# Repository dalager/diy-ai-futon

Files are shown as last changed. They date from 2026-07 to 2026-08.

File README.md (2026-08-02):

# Sengebund — LET variant (futon 180 × 200 cm)

Parametrisk CAD-projekt for en let, ubehandlet **futon-sengebund**: slank 45×95-ramme,
17 kvadratiske 45×45-lameller der flugter med rammens overkant, og en langsgående
midterdrager (45×45) på ét midterben. Ben skæres af afskær (45×95) — ingen
trykimprægneret stolpe, ingen lim. Udvendige mål = madrasmålet (180 × 200 cm), så
madrassen ligger plant af med kanten.

Hele modellen bygges headless i **FreeCAD** fra ét parametersæt, og tegninger,
boreplan, renderinger og en samlet PDF genereres af scripts.

| Isometrisk | Understel (lameller skjult) |
|:---:|:---:|
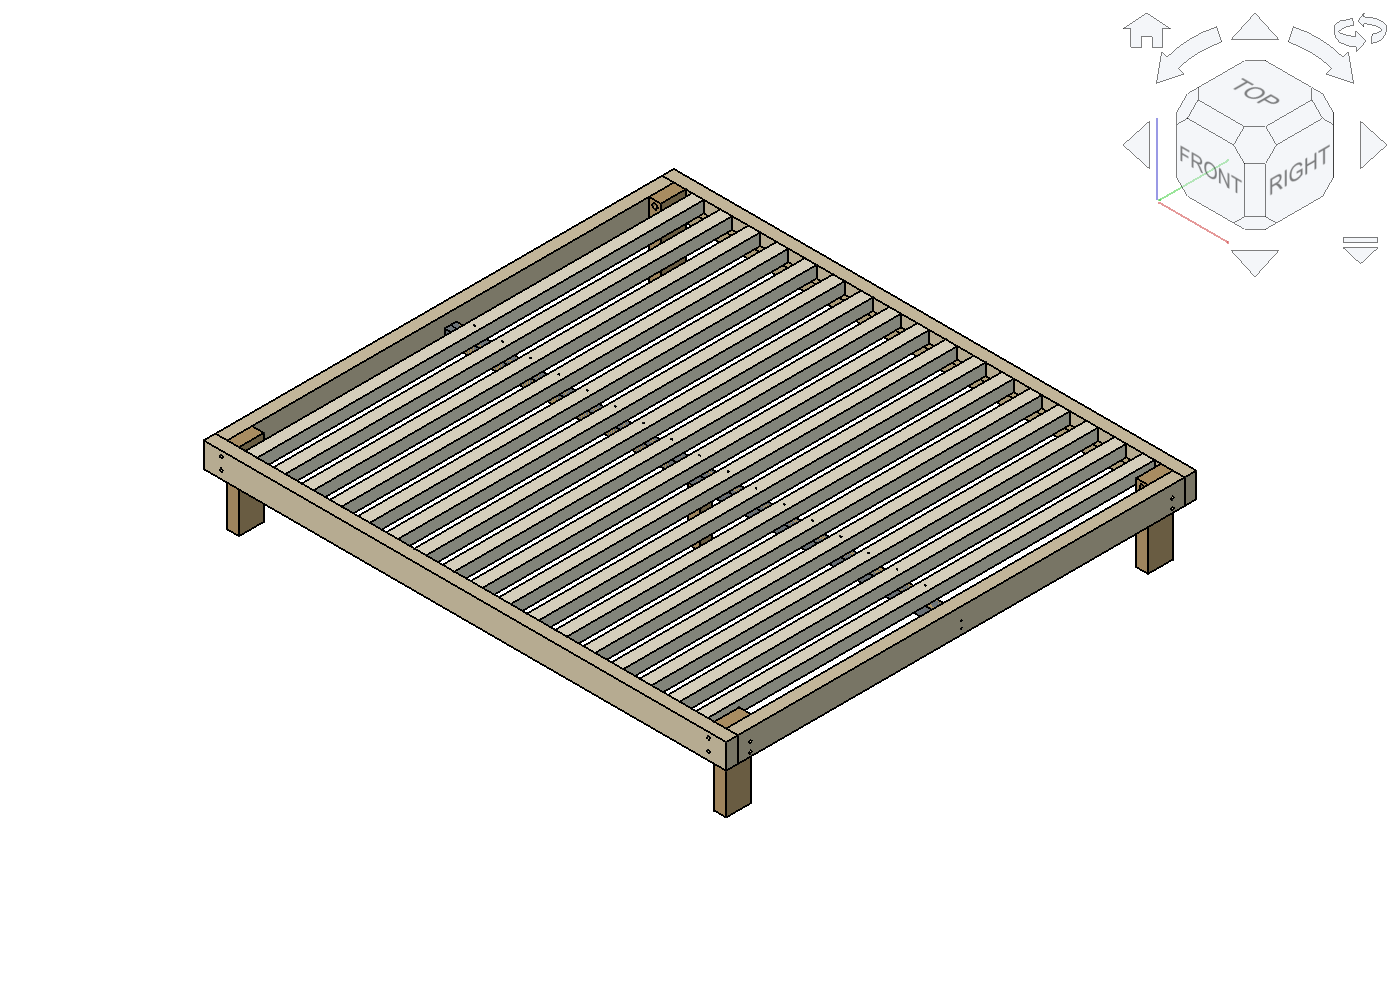
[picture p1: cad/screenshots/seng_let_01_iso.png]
Isometrisk
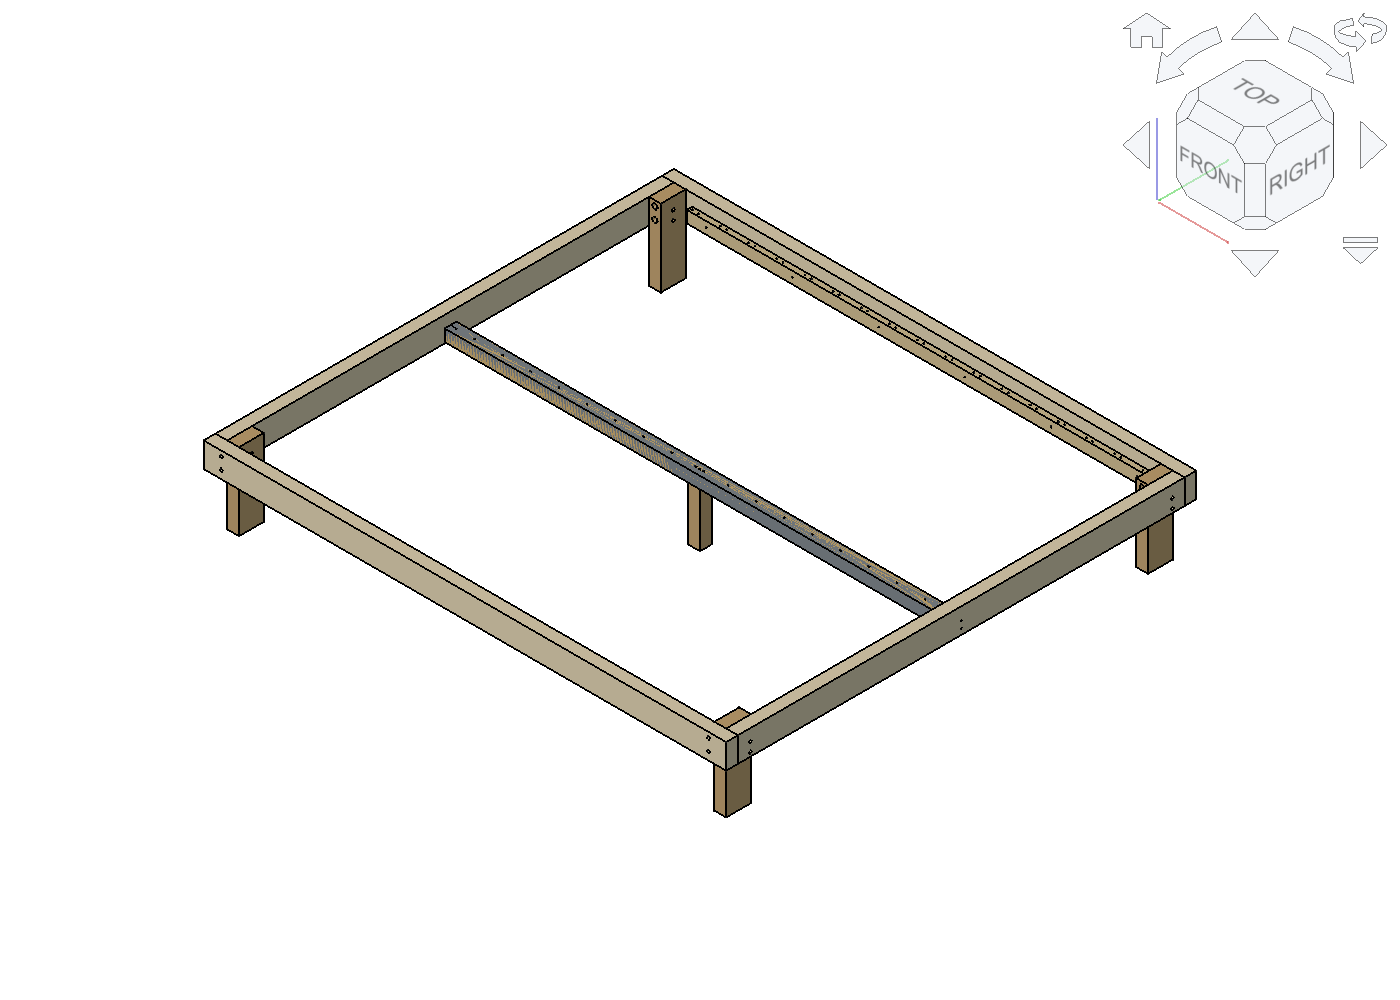
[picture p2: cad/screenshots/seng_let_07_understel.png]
Understel
|  |  |

## Kort specifikation

| | |
|---|---|
| Udvendige mål | 180 × 200 cm (= madras, flush) |
| Vægt | ~48 kg (fyr/gran) |
| Ramme | 45 × 95, boltet i hjørnerne (M10) |
| Lameller | 17 × 45×45, flugter med rammens overkant |
| Midtersupport | drager 45×45 + ét midterben |
| Frihøjde | 200 mm under ramme / 205 mm under drager (robotstøvsuger) |
| Ben | 4 × 45×95 af **afskær** ♻️ (ubehandlet, ingen lim) |
| Pris (jul. 2026) | ~1.650 kr (træ prischecket, skruer anslået) |

## Dokumenter

- **[byggevejledning.md](byggevejledning.md)** — vejledningen til udlevering: indkøb,
  værktøj, skæreplan, boring, samling trin for trin, kontrol og statik-tjek.
- **[docs/dokumentation.pdf](docs/dokumentation.pdf)** — byggevejledningen
  som A4-PDF med renderinger og de fire målsatte tegninger bagest (genereres, se nedenfor).
- **[designnoter.md](designnoter.md)** — arbejdsnote uden for PDF'en: hvorfor
  konstruktionen ser ud som den gør, statik, dimensionering, forkastede løsninger og
  indkøbsregnskab.

## Projektstruktur

```
seng/
├── byggevejledning.md            # byggevejledning (kilde til PDF'en)
├── designnoter.md                # arbejdsnote (valg, statik, indkøbsregnskab)
├── scripts/
│   ├── build_bed_let.py          # bygger 3D-modellen -> .FCStd + .step
│   ├── make_drawing_let.py       # målsat tegning -> docs/tegning.svg
│   ├── make_drilling_plan_let.py # boreplan -> docs/boreplan.svg
│   ├── add_drawing_page_let.py   # TechDraw-sider ind i .FCStd
│   └── make_pdf_let.py           # byggevejledning -> PDF (+ tegninger bagest)
├── cad/                          # kun CAD-kilder
│   ├── seng_let.FCStd            # FreeCAD-model (parametrisk, med huller)
│   ├── seng_let.step             # neutral CAD-udveksling
│   └── screenshots/              # 8 FreeCAD-renderinger (.png)
└── docs/                         # genererede tegninger + PDF
    ├── tegning.svg               # målsat tegning
    ├── boreplan.svg              # boreplan (paneler A-D)
    ├── liste_boreplan.svg        # boreplan, støttelistens lamelhuller
    ├── drager_boreplan.svg       # boreplan, midterdrager -> endestykke (vinkelbeslag)
    └── dokumentation.pdf         # byggevejledningen
```

`docs/` rummer desuden referencefotos af beslag og skruer (`*.png`), som er
git-ignorerede — kun de genererede tegninger og PDF'en versionsstyres.

## Genopbygning af hele kæden

Alt afledes af parametrene øverst i `scripts/build_bed_let.py` (mål, antal lameller,
profiler). Ret dem og genkør kæden i rækkefølge:

```bash
# 1. Byg 3D-modellen (headless FreeCAD) -> cad/seng_let.FCStd + .step
freecad.cmd scripts/build_bed_let.py

# 2. Målsat tegning (ren Python) -> docs/tegning.svg
python3 scripts/make_drawing_let.py

# 3. Boreplan (ren Python) -> docs/boreplan.svg + docs/drager_boreplan.svg
python3 scripts/make_drilling_plan_let.py

# 4. TechDraw-sider ind i .FCStd (headless FreeCAD)
freecad.cmd scripts/add_drawing_page_let.py

# 5. Byggevejledning som PDF (byggevejledning.md + de fire tegninger bagest)
~/.pyenv/versions/3.12.3/bin/python scripts/make_pdf_let.py
```

### Renderinger (FreeCAD GUI)

De 8 screenshots i `cad/screenshots/` tages i FreeCAD-GUI'en (via freecad-MCP), fordi
farver og kamera kræver et grafisk miljø. Efter en headless genopbygning (trin 1)
skal modellen genindlæses i GUI'en, træfarverne påføres pr. byggegruppe, filen gemmes,
og de 8 views eksporteres med `View3DInventor.saveImage(...)`.

Farvepaletten (matcher tegningerne):

| Del | Farve |
|-----|---|
| Ramme | `#d8c9a8` |
| Ben (inkl. midterben) | `#b99763` |
| Støttelister | `#c9b487` |
| Lameller | `#efe7d3` |
| Midterdrager | `#c2a266` |

## Afhængigheder

- **FreeCAD** (snap: `freecad.cmd` til headless build; GUI til renderinger).
- **freecad-mcp** ([neka-nat/freecad-mcp](https://github.com/neka-nat/freecad-mcp)) —
  renderingstrinnet styres via FreeCAD-MCP-serveren, så en agent/klient kan genindlæse
  modellen, sætte farver og kalde `saveImage(...)` i den kørende FreeCAD-GUI.
  **Serveren er ikke checket ind i dette repo** (ligger i `deps/freecad-mcp`, som er
  git-ignoreret) — klon den fra upstream og konfigurér den i `.mcp.json`; FreeCAD-GUI'en
  skal køre med MCP-addon'et aktivt:
  ```bash
  git clone https://github.com/neka-nat/freecad-mcp.git deps/freecad-mcp
  ```
  (Selve build- og tegningsscriptene kræver **ikke** MCP — kun de 8 screenshots i
  `cad/screenshots/`.)
- **Python** til tegningerne (kun standardbibliotek).
- **PDF:** `markdown`, `pymdown-extensions` og `weasyprint` — installeret i pyenv-miljøet
  `~/.pyenv/versions/3.12.3`. Kør `make_pdf_let.py` med netop den python. Fonte:
  DejaVu Sans Mono (ASCII-diagrammer) + Noto Color Emoji (♻️ ✅ ⚠️).

## Noter

- **Træfarver er ikke persistente over en headless genopbygning:** trin 1 skriver et
  nyt `.FCStd` uden ViewObject-farver (headless FreeCAD kan ikke sætte dem). Påfør dem
  igen i GUI'en efter genopbygning, før du tager screenshots.
- **Midterdrager 45×45** er et bevidst valg: den flush lamel ville med en 45×70-drager
  kun give 180 mm frihøjde under midten; 45×45 bevarer 205 mm og bruger samme profil
  som lamellerne. Til gengæld er drageren et grænsetilfælde omkring L/300 — se
  statik-afsnittet i [designnoter.md](designnoter.md).

## Licens

[MIT](LICENSE) © 2026 Christian Dalager

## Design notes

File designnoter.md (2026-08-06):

# Designnoter — sengebund LET, futon 180 × 200 cm

Arbejdsnote til **hvorfor** sengen ser ud som den gør: konstruktionsvalg, statik,
dimensionering, forkastede løsninger og indkøbsregnskab.

**[byggevejledning.md](byggevejledning.md) er facit** for mål, hulplaceringer,
materialeliste og fremgangsmåde. Denne note gentager dem ikke — ret altid vejledningen
først, og skriv kun begrundelsen her. Selve geometrien kommer fra
`scripts/build_bed_let.py`, og CAD-modellen (`cad/seng_let.FCStd`) er sandheden om
hulplaceringer.

## Parametersæt

Alt afledes af `P` i `scripts/build_bed_let.py`:

| Parameter | Værdi | Bemærkning |
|---|---|---|
| `clearance` | 200 | frihøjde til gulv |
| `rail_h` / `rail_t` | 95 / 45 | rammens profil (var 120 i den tunge variant) |
| `outer_len` | 2000 | = madraslængden, flush |
| `inner_w` | 1710 | → udvendig bredde 1800 = madrasbredden |
| `ledger_t` / `ledger_h` | 21 / 45 | støtteliste, 45 mm står lodret |
| `slat_t` / `slat_h` | 45 / 45 | kvadratisk lamel |
| `n_slats` | 17 | → c/c 107,8 mm, spalte 62,8 mm |
| `drager_t` / `drager_h` | 45 / 45 | samme profil som lamellerne |

Afledte kotehøjder: soveflade og rammens overkant 295, lamel-underkant og
støtteliste-overkant 250, rammens underkant 200, dragerens underkant 205.

## Konstruktionsvalg

**Udvendige mål = madrasmålet.** Madrassen ligger plant af med kanten i stedet for at være
indelukket af en liste. Det gør rammen til det synlige møbel og sparer 90 mm i begge
retninger. Konsekvensen er, at lamellerne skal flugte med rammens overkant, ikke ligge nede
i den.

**Kvadratiske 45×45-lameller.** Slankhed 1:1 kan ikke vælte, så dominoeffekten fra høje,
tynde lameller findes ikke, og skruerne i enderne er ren lås uden at bære vægt. Prisen er,
at en 45×45 ikke kan spænde 1710 mm alene — den kræver midtersupport. Lamellerne er også
den dyreste post i materialelisten (45×45-reglar er dyre pr. bræt).

**Midterdrager på ét midterben.** Halverer det frie lamelspænd fra 1710 til ~810 mm, og
det er den ene ændring, der gør de kvadratiske lameller mulige. Lamellerne er kontinuerte
over drageren, hvilket gør dem stivere end to fritliggende fag.

**Drager 45×45 frem for 45×70 på højkant.** Kvadratisk drager holder frihøjden på 205 mm
under midten; en 45×70 med samme overkant ender i kote 180 og bryder altså 20 cm-kravet fra
robotstøvsugeren. Det koster stivhed — se statikken. Sidegevinst: kun to reglar-tværsnit i
hele projektet, 45×45 og 45×95.

**20 cm frihøjde** er sat af støvsugerrobotten, ikke af æstetikken. Dragerens underkant
ligger 5 mm over rammens underkant, så der er fri passage overalt.

**Ben af afskær.** Der fandtes ingen firkantet, ubehandlet stolpe hos jem&fix, Silvan eller
Bauhaus — alle massive stolper er trykimprægnerede eller malede. Afskærene fra vanger,
endestykker og drager giver præcis de fem ben, sengen skal have, og resultatet er 100 %
ubehandlet og lim-frit. Ben-tværsnittet 45×95 er slankt for et sengeben, men rammen er en
stiv boltet kasse, så benene står i ren tryk.

**Boltede hjørner, ikke skruede.** Fire gennemgående bolte pr. hjørne kan efterspændes,
når ubehandlet fyr svinder det første år. Skruer i endetræ kan ikke. Det er også derfor,
vange-aksen har kontramøtrik.

## Statik

Fyr, E ≈ 10 GPa, regnet på CAD-modellens geometri. Komfortgrænsen L/300:

| Del | Frit spænd | Nedbøjning ved fuld last | L/300 |
|-----|---|---|---|
| Lamel 45×45 | 810 mm | ~1,7 mm (50 kg punktlast midt på ét fag) | 2,7 mm |
| Midterdrager 45×45 | 2 fag à 955 mm | ~3–4 mm pr. fag | ~3,2 mm |
| Vange 45×95 | 1910 mm | 1–2 mm | ~6,4 mm |

**Drageren er et grænsetilfælde** lige omkring L/300 — designets svageste punkt.
Vurderingen er, at det er uproblematisk under en eftergivende futon, men det er et bevidst
valg for at holde frihøjden. Vil man have margin: et ekstra midterben koster kun et hul og
ingen frihøjde; 45×70 på højkant er stivere, men sender frihøjden under midten ned på
180 mm.

Vangen er kraftigt overdimensioneret, og drageren afstiver den desuden på midten.

**Bolte:** totallasten er ~2,3 kN fordelt på fire hjørner = ~600 N pr. hjørne på to bolte.
Grænsen sættes ikke af bolten (en M8 tåler ~8,8 kN i forskydning) men af **træets
hulrandstyrke**: 8 mm × 45 mm × ~25 MPa ≈ 9 kN for M8, ~11 kN for M10. Begge ligger 15–30
gange over behovet, så de 2 mm boltdiameter er uden betydning. Det, der betyder noget, er
**skivens størrelse** — en M8-planskive er kun Ø16, og møtrikken trækker sig ind i træet.
Derfor Ø24 karosseri-/firkantskive på endestykke-aksen.

## Skruerne — hvorfor tre længder

103 skruesamlinger: **85 × 4,5×60**, **12 × 4,5×50**, **6 × 5×80**.

- **4,5 × 60** til lamel → liste og lamel → drager. 45 mm nær-del + 15 mm fat. Begge
  samlinger *hviler*, så skruen bærer nul vægt og er ren lås; 15 mm i sidetræ er rigeligt.
- **4,5 × 50** til støtteliste → vange. Den eneste samling, der går **vandret** gennem
  listens 21 mm: 21 + 45 = 66 mm stak, så en 70'er stikker 4 mm ud på vangens yderside, og
  en 60'er efterlader kun 6 mm. 50 giver 29 mm fat og 16 mm margin.
- **5 × 80** til drager → endestykke og drager → midterben. De eneste samlinger i
  **endetræ**, hvor holdeevnen er 50–75 % af sidetræs: 35 mm fat i stedet for 15. Der er
  ubegrænset plads bagved (drageren 1910 mm, midterbenet 205 mm), så længden koster
  ingenting.

**Forboringsreglerne** bag tallene i vejledningen, i fyr/gran: gennemgang = skruediameter
+ 0,5 mm; pilot ≈ 65 % af skruediameteren; forsænkning Ø ≈ 2 × skruediameteren.
Undtagelsen er 5×80-skruerne, hvis hoved er Ø10 — dér skal forsænkningen være Ø11, for en
Ø10-forsænkning er lige præcis for lille. 4,5-skruerne har Ø9-hoved, hvor Ø10 rækker.

**Delgevind redder ikke samlingen — forboringen gør.** En 4,5×60 delgevind har kun ~20–25
mm glat skaft, men skruen skal gennem 45 mm nær-del, så gevindet starter inde i nær-delen
alligevel. Det er Ø5-gennemgangshullet, der lader gevindet spille frit og hovedet trække
delene sammen. Delgevind er en fordel oveni, ikke en erstatning. Samme grund til at listens
huller **skal** være Ø5 og ikke Ø4: med Ø4 griber gevindet i listen og jækker de to dele
fra hinanden i stedet for at spænde dem sammen.

**Krav ved genkøb:** spånskrue/universalskrue, undersænket hoved, Torx, delgevind.
Elforzinket rækker indendørs; rustfri er kun nødvendigt udendørs, og Impreg®+ er en
udendørs-coating — mere end nødvendigt, men uskadeligt. Vinkelbeslagene er undtagelsen:
beslagskruer med **fladt** hoved, da en undersænket skrue trækker sig ned i beslagets hul
og kan flække det.

## Bolteakserne

Fordi hjørnebenet er 45×95 af afskær, er de to akser forskellige:

**Vange-aksen: M10 × 160** gennem vange (45) + ben (95) = 140 mm træ. Der stikker 20 mm ud
på benets inderflade, hvor skive 2,5 + møtrik 8 + kontramøtrik 8 = 18,5 mm — reelt plant,
ingen forsænkning. Kontramøtrikken er der, fordi ubehandlet fyr svinder, og boltede
træsamlinger løsner sig, når træet krymper. Alternativ: hattemøtrik, der dækker gevindet
helt.

**Endestykke-aksen: M8 × 100** gennem endestykke (45) + ben (45) = 90 mm. Møtrik + Ø24
skive sidder fladt på indersiden. Kun **1,5 mm gevind til overs**, så ingen kontramøtrik og
ingen nyloc på den akse (en M8 nyloc er ~8 mm høj og løber tør for gevind) — og hjørnet
skal presses helt sammen, før møtrikken sættes på. Boltene sidder ved x < 90, mens første
lamel starter ved x = 115, så møtrikkerne går fri af lamelfeltet.

**Hullerne er Ø12 og Ø10, ikke Ø11 og Ø9.** De "rigtige" størrelser er ikke altid til at
skaffe, så næste almindelige størrelse op blev valgt. To konsekvenser: bræddeboltens
firkanthals (M10 ~11,9 mm, M8 ~9,2 mm) **bider ikke** længere, så bolten skal holdes med en
tang, når møtrikken spændes — og marginen i boltkrydset faldt fra 5 til **4 mm** træ mellem
de to huller (de krydser vinkelret med 15 mm lodret afstand). Derfor kravet om vinkelret
boring og om at bore alle fire huller i et ben, før nogen bolt sættes i.

## Forkastede løsninger

Samlet her, så byggevejledningen ikke skal diskutere med sig selv:

| Forkastet | Erstattet af | Hvorfor |
|---|---|---|
| Ramme 45×120 | 45×95 | vægt og udseende; 95 rækker statisk, når der er drager |
| Drager 45×70 på højkant | 45×45 | frihøjde 205 mm under midten; koster stivhed |
| Vinkelbeslag + 6×120 til midterbenet | 2 × 5×80 lodret ned | kravet gjaldt kun den 70 mm høje drager; den 45 mm høje giver 35 mm fat |
| M10 × 140 på vange-aksen | M10 × 160 | 140 mm bolt i 140 mm træ = nul gevind til møtrikken |
| Ø20-lomme i benets inderside | ingen forsænkning | en M10-møtrik kræver en top på 23–25 mm, som ikke kommer ned i Ø20; en større lomme bryder ind i endestykke-boltens hul 15 mm under. **Ø20-forstnerboret er derfor ude af værktøjslisten** |
| Ø11/Ø9 bolthuller | Ø12/Ø10 | kan ikke altid skaffes; koster 1 mm i boltkrydset og firkanthalsens greb |
| Trykimprægneret stolpe til ben | afskær 45×95 | ingen ubehandlet firkantstolpe fandtes; ubehandlet og lim-frit var kravet |
| Kombineret undersænkbor | løs kegleforsænker 90° Ø16 | nær-del og fjern-del skal have to forskellige diametre i samme hul |

Der findes intet mellem M10×140 og ×160: en ×120 når ikke gennem de 140 mm træ, og næste
trin op er ×200, som ville stritte 60 mm ud.

## Indkøbsregnskab

Priser fra Silvan.dk (juli 2026, ekskl. levering). Alt er købt hos Silvan bortset fra
vange-boltene.

### Træ — 1.376,40 kr

| Vare | Antal | Pris/stk | I alt |
|---|---|---|---|
| [Reglar 45×45×2400 ubeh.](https://www.silvan.dk/produkt/froeslev-reglar-45x45x2400-mm-ubehandlet-hoevlet-7700-9804949) | 18 | 64,80 | 1.166,40 |
| [Reglar 45×95×2400 ubeh.](https://www.silvan.dk/produkt/froeslev-reglar-45x95x2400-mm-ubehandlet-hoevlet-7700-9804953) | 4 | 43,80 | 175,20 |
| [Forskalling 21×45×2400 ubeh.](https://www.silvan.dk/produkt/froeslev-forskalling-21x45x2400-mm-ubehandlet-hoevlet-7700-9804930) | 2 | 17,40 | 34,80 |
| Ben (4 hjørne + 1 midter) | 0 | — | 0 |

### Skruer, bolte og beslag — købt hos Silvan

| Vare | Varenr. | Pakke | Bruges | Tilovers |
|---|---|---|---|---|
| Simpson TTZNFS 4,5 × 60 | 74485 | 200 stk | 85 | 115 |
| Simpson TTZNFS 4,5 × 50 | 74484 | 200 stk | 12 | 188 |
| Simpson TTZNFS 5,0 × 80 | 76540 | 100 stk | 6 | 94 |
| Simpson TTUFP 4,0 × 20 beslagskruer | 74519 | 200 stk | ~16 | ~184 |
| KRAM bræddebolt M8 × 100 m/ møtrikker | 6774056 | 12 stk | 8 | 4 |
| KRAM spændeskive M8, 8,4 × 24 × 2,0 | 6774773 | 30 stk | 8 | 22 |
| KRAM spændeskive M10, 10,5 × 30 × 2,5 | 6774774 | 15 stk | 8 | 7 |
| Simpson AC35350 vinkelbeslag | — | 2 stk | 2 | 0 |

Overskuddet er stort, fordi skruerne ikke fandtes i mindre pakker i de længder. De faktiske
priser på skruer og beslag er ikke registreret.

### Mangler — hentes hos jem&fix

| Vare | Antal | Pris |
|---|---|---|
| NKT bræddebolt DIN 603 M10 × 160, 2-pak à 39,95 | 8 stk (4 pk) | **159,80 kr** |
| Løse M10-møtrikker til kontramøtrik | 8 | ~25 kr |

**I alt ca. 1.650 kr** for en 100 % ubehandlet, lim-fri sengebund med ben af genbrugte
afskær.

## Åbne punkter

- **Vinkelbeslag:** Simpsons datablad anbefaler 2 beslag pr. samling (ét i hver side af
  drageren). Der er købt 2 i alt, altså ét pr. ende. To ekstra beslag koster lidt og øger
  sikkerhedsmarginen på den samling, hvis anbefalingen skal følges fuldt ud.
- **Dragerens nedbøjning** ligger på L/300-grænsen. Bør vurderes efter en sæsons brug.
- **De 2 skruer ned i midterbenet** sidder ±15 mm fra midten i CAD-modellen, altså 7,5 mm
  fra benets kant i endetræ. Bores der i hånden, kan de flyttes ind til ±10 mm — så skal
  dragerens gennemgangshuller flyttes tilsvarende.
- **Skruepriserne** er ikke prischecket, så totalen er et skøn.

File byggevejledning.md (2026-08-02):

# Sengebund til futon 180 × 200 cm

Let, ubehandlet futon-sengebund i fyr/gran: slank **45×95-ramme** boltet i hjørnerne,
**17 kvadratiske 45×45-lameller** der flugter med rammens overkant, og en langsgående
**midterdrager på ét midterben**, der halverer lamelspændet. Udvendige mål er
madrasmålet, så madrassen ligger plant af med kanten — ingen liste op om.

Ingen lim, ingen trykimprægneret træ og ingen avanceret træbearbejdning: **alle snit er
lige**, og alle samlinger er skruet eller boltet. Benene skæres af afskærene, så du
køber intet træ til dem.

<div class="figrow">
<figure>Isometrisk<figcaption>Færdig sengebund</figcaption></figure>
<figure>Understel<figcaption>Understel — lameller skjult</figcaption></figure>
</div>

| Kort fortalt | |
|---|---|
| Udvendige mål | 1800 × 2000 mm (= madrassen, flush) |
| Sovehøjde | 295 mm bund + 15–18 cm futon ≈ 45 cm |
| Frihøjde til gulv | 200 mm under rammen, 205 mm under drageren |
| Vægt | ~48 kg |
| Træ | 22 reglar + 2 forskallingsbrædder, ubehandlet fyr/gran |
| Fastgørelse | 103 skruer i tre længder + 16 gennemgående bolte + 2 vinkelbeslag |
| Pris | ~1.650 kr (juli 2026) |
| Sværeste opgave | de 8+8 bolthuller i benene — de skal bores vinkelret |

**Rækkefølgen i vejledningen er arbejdsrækkefølgen:** indkøb → værktøj → skæreplan →
boring → samling → kontrol. Bagest ligger fire målsatte tegninger og et statik-tjek.
Boringen er det store stykke arbejde (103 huller plus forsænkninger); samlingen går
hurtigt, når hullerne sidder.

## 1 · Sådan er sengen bygget {: .newpage }

```
      ← 200 cm (længde) →
   ┌────────────────────────────┐   ┐
   │ ▪  ▪  ▪  ▪  ▪  ▪  ▪  ▪  ▪  ▪ │   │  ← 45×45 lameller (17 stk)
   │ ═══════ midterdrager ══════ │   │     spænder tværs, hviler på
   │ ▪  ▪  ▪  ▪  ▪  ▪  ▪  ▪  ▪  ▪ │   │     3 punkter: liste-drager-liste
   └────────────────────────────┘   ┘  180 cm (bredde)
   ▙             ▪              ▟
   ben        midterben         ben
```

- **To vanger 45×95 + to endestykker** boltes sammen om 4 hjørneben = en stiv kasse.
- **Støttelister 21×45** skrues på vangernes indersider og bærer lamelenderne.
- **Midterdrageren 45×45** løber i længderetningen på ét midterben og halverer
  lamellernes frie spænd fra 1710 mm til ~810 mm.
- **Lamellerne 45×45** flugter med rammens overkant. Det halverede spænd gør den lille
  kvadratiske profil stiv nok, og et kvadratisk tværsnit kan ikke vælte. Madrassen
  hviler plant på ramme og lameller i samme kote.

### Højder (alle mål fra gulv)

```
   top af lameller = top af ramme  295 mm  ┄┄┄┄ sovefladen (lameller flugter med rammen)
   lamel-underkant                 250 mm  ─────┐
   støtteliste-overkant            250 mm       │  vange 95 mm
   underkant ramme                 200 mm  ─────┘  ← 20 cm FRIHØJDE
   underkant drager (45×45)        205 mm  ─────   ← 5 mm over rammens underkant
   gulv                              0 mm  ▂▂▂▂▂▂
```

Hjørnebenene er derfor **295 mm** (200 + 95) og midterbenet **205 mm**. Frihøjden er
200 mm under rammen og 205 mm under drageren, så en robotstøvsuger på 20 cm går fri
overalt — også under midten.

<div class="figrow">
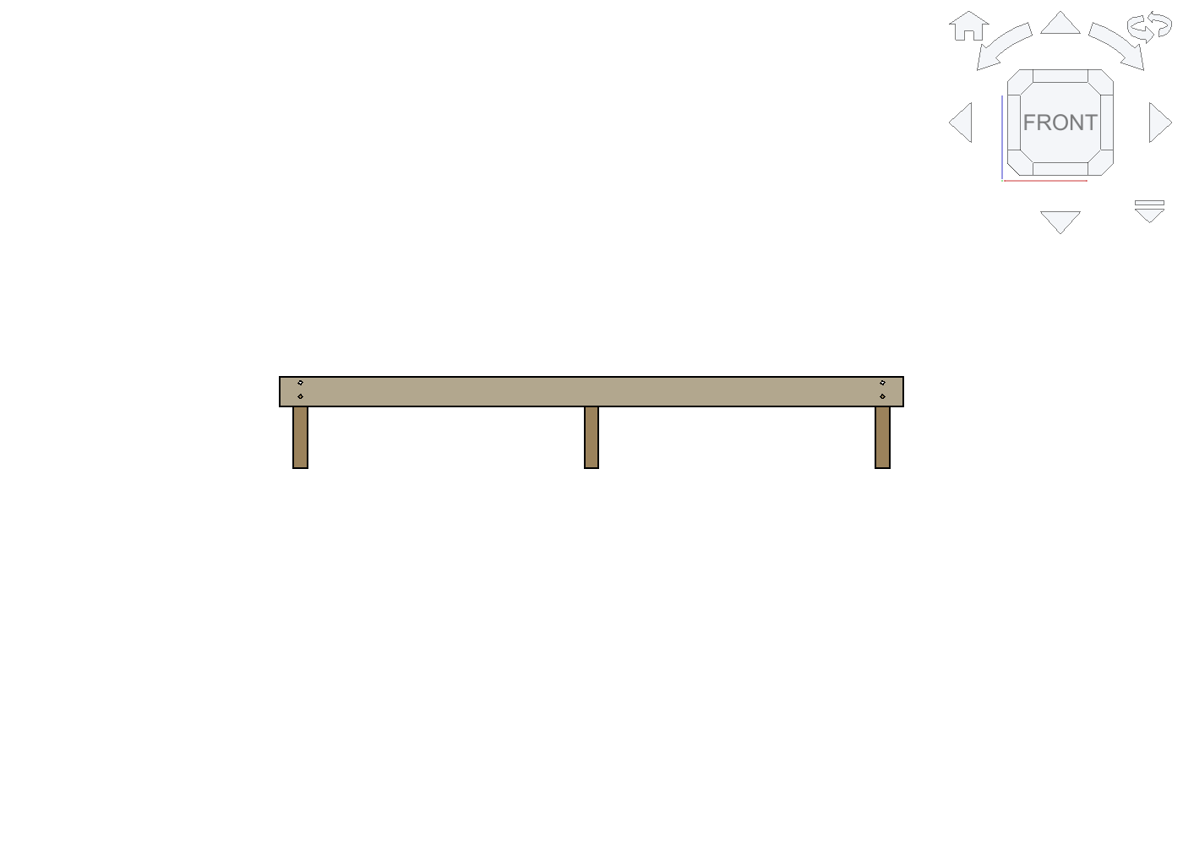
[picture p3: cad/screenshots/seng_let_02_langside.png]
Langside
<figure><figcaption>Langside</figcaption></figure>
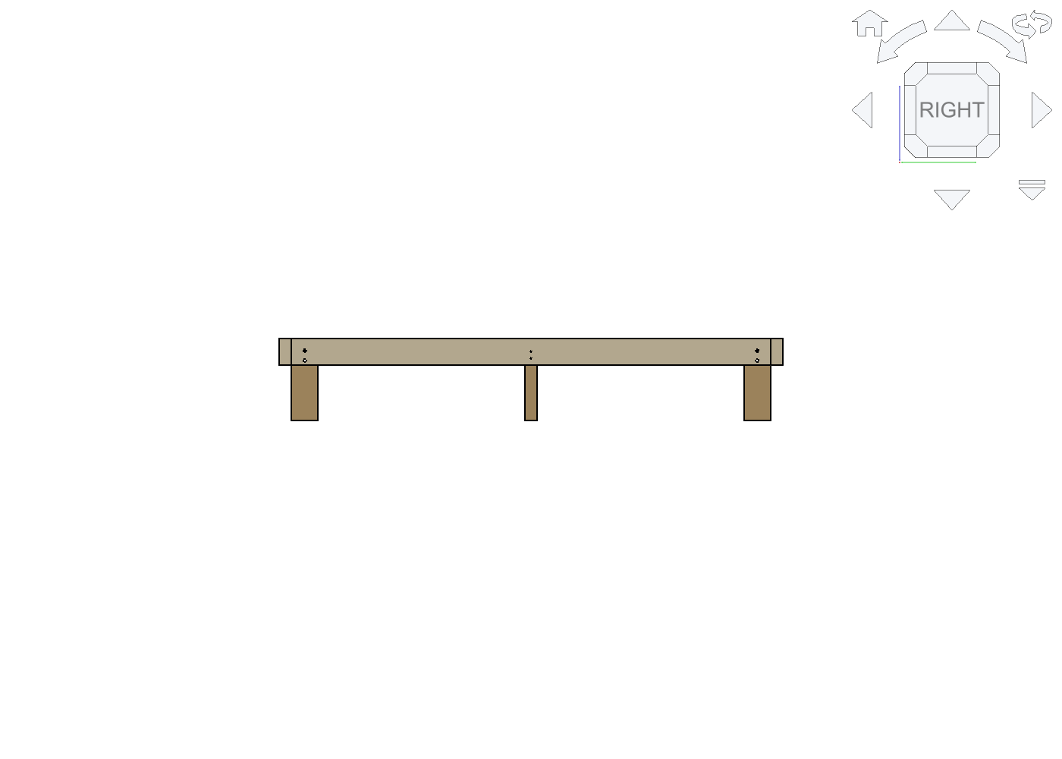
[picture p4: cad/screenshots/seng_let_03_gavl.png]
Gavl
<figure><figcaption>Gavl</figcaption></figure>
</div>

## 2 · Indkøb

### Træ (fyr/gran, ubehandlet, høvlet)

| Vare | Antal | Pris/stk | I alt | Bruges til |
|---|---|---|---|---|
| Reglar 45×45×2400 ubeh. | 18 | 64,80 | 1.166,40 | 17 lameller + 1 midterdrager |
| Reglar 45×95×2400 ubeh. | 4 | 43,80 | 175,20 | 2 vanger + 2 endestykker |
| Forskalling 21×45×2400 ubeh. | 2 | 17,40 | 34,80 | 2 støttelister |
| Ben (4 hjørne + 1 midter) | 0 | — | 0 | **skæres af afskærene** ♻️ |

**Træ i alt 1.376,40 kr** (Silvan, juli 2026, ekskl. levering). Der er kun to
reglar-tværsnit at holde styr på: 45×45 til lameller og drager, 45×95 til rammen.

### Vælg træ, der er lige — især de fire 45×95

Reglar er en byggevare, ikke en møbelvare, og bunken i byggemarkedet er blandet. **Sortér
selv, og læg de dårlige tilbage.** Sigt langs hvert bræt fra enden — først på fladen, så på
højkant — og drej det derefter om sin egen akse. Læg det på et plant gulv og se, om det
vipper på diagonalen.

- **Vrid (snoning)** — enderne er drejet i forhold til hinanden. Den værste fejl her, og
  den eneste, du ikke kan skrue væk.
- **Svaj** — buet på højkant, "banan". Giver en ramme, hvis diagonaler ikke vil passe.
- **Krumning** — buet på fladen. Til at leve med; skruerne trækker en mindre bue ud.
- **Skålning** — hulning på tværs. Uden betydning i disse tværsnit.

Det er **de fire 45×95** til vanger og endestykker, det gælder. De sætter rammens geometri,
og et vrid dér forplanter sig gennem hele sengen: hjørnerne kommer skævt sammen, benene
hælder en anelse, og støttelistens overkant følger vangens vrid, så lamelfladen ikke bliver
helt plan. Sengen holder fint — de boltede hjørner er stærke nok til at tvinge træet på
plads — men vridet kan ses. 45×45-lamellerne er mere tilgivende: de er understøttet tre
steder og skruet fast i begge ender, så en let bue rettes ud af samlingen.

Et roligt bræt kendes på, at årerne løber nogenlunde parallelt med kanten, at **marven**
(den bløde kerne, der ses som tætte cirkelbuer i endetræet) ikke er med i brættet, og at
det føles tørt og let. Marvholdt eller fugtigt træ vrider sig, når det tørrer — også efter
sengen er bygget. Husk også, at benene skæres af afskærene: et vridt endestykke giver et
vridt ben. Lad træet ligge en uges tid indendørs, hvor sengen skal stå, stablet plant og
med luft omkring, før du skærer op — så sker det meste af bevægelsen, inden delene er i mål.

### Skruer, bolte og beslag

| Vare | Køb | Bruges |
|---|-----|---|
| Spånskrue 4,5 × 60 (fx Simpson TTZNFS, art. 74485) | 200-pak | 85 |
| Spånskrue 4,5 × 50 (art. 74484) | 200-pak | 12 |
| Spånskrue 5,0 × 80 (art. 76540) | 100-pak | 6 |
| Beslagskrue 4,0 × 20, **fladt** hoved (Simpson TTUFP, art. 74519) | 200-pak | 16 |
| Bræddebolt **M10 × 160** DIN 603 (jem&fix, NKT) | 4 × 2-pak à 39,95 = **159,80 kr** | 8 |
| Løse **M10-møtrikker** til kontramøtrik | 8 stk (~25 kr) | 8 |
| Spændeskive M10, 10,5 × 30 × 2,5 | 15-pak | 8 |
| Bræddebolt **M8 × 100** m/ møtrik | 12-pak | 8 |
| Spændeskive M8, **8,4 × 24** × 2,0 | 30-pak | 8 |
| Vinkelbeslag Simpson AC35350 | 2 stk | 2 |

Alle skruer skal være **spånskruer med undersænket hoved, Torx og delgevind**.
Elforzinket rækker fint indendørs; rustfri er kun nødvendigt udendørs. Beslagskruerne
er undtagelsen — de skal have **fladt** hoved, for en undersænket skrue trækker sig ned
i beslagets hul og kan flække det.

Pakkestørrelserne giver rigeligt overskud. Det var det billigste: skruerne findes ikke
i mindre pakker i de længder.

⚠️ **Køb M10 × 160 til vangerne — ikke M10 × 140.** Vange-aksen går gennem 45 + 95 =
140 mm træ, så en 140 mm bolt ender præcis plant med træet og har nul gevind tilbage
til møtrikken. 160 mm giver de 20 mm, der skal til skive + møtrik + kontramøtrik.
jem&fix har dem kun i 2-pak, og der findes intet mellem 140 og 160 (en M10 × 200 ville
stritte 60 mm ud).

**Skiverne skal være store.** En almindelig M8-planskive er kun Ø16 og trækker sig ind
i træet — derfor Ø24 på endestykke-aksen. Skiven gør mere for samlingen end
boltdiameteren.

## 3 · Værktøj og bor

- **Kap-/geringssav eller rundsav med anslag** — 23 lige snit, ingen geringer
- **Søjleboremaskine eller borelære** — nødvendig til benenes bolthuller, se
  advarslen om boltkrydset i afsnit 5
- **Boremaskine + skruemaskine** med Torx-bit (størrelsen står på skruepakken)
- **Bor:** Ø2,5 · Ø3 · Ø3,5 · Ø5 · Ø5,5 · Ø10 · Ø12
- ⚠️ **Ø10 og Ø12 skal være lange bor:** de går gennem 90 hhv. **140 mm** træ i én
  gennemgang. Et almindeligt 100 mm-spiralbor rækker ikke — brug et slangebor eller et
  langt spiralbor med mindst 160 mm nyttelængde
- **Én kegleforsænker 90°, Ø16, HSS, sekskantskaft** (~60–100 kr)
- **Fastnøgle/top 13 mm** (M8) og **17 mm** (M10) + en tang til at holde boltehovedet
- Båndmål (5 m), vinkel, blyant, mindst 4 skruetvinger, malertape (til at markere
  boredybde), sandpapir 120
- **To bukke, kasser eller stole** at sætte sengen op på, når lamellerne skal skrues
  fast nedefra

**Køb ikke et kombineret undersænkbor.** Det borer forhul og forsænker i én bevægelse
med én diameter — men her skal den nære del have Ø5 gennemgang og den fjerne Ø3 pilot,
altså to diametre i samme hul. En løs kegleforsænker er den rigtige.

## 4 · Skæreplan

Skær alt op først, og **mærk afskærene op med det samme** — de fem ben kommer af dem.

| Emne | Køb | Skæres til | Afskær |
|---|-----|---|---|
| Lameller | 17 × 45×45×2400 | 1 à **1710** pr. stk | 17 × 690 (overskud) |
| Midterdrager | 1 × 45×45×2400 | 1 à **1910** | **1 × 45×45×490 → midterben** |
| Vanger | 2 × 45×95×2400 | à **2000** | **2 × 45×95×400 → hjørneben** |
| Endestykker | 2 × 45×95×2400 | à **1710** | **2 × 45×95×690 → hjørneben** |
| Støttelister | 2 × 21×45×2400 | à **1770** | 2 × 630 (overskud) |

### Ben af afskær (køb intet nyt træ ♻️)

| Ben | Antal | Skæres af | Længde |
|-----|---|---|---|
| Hjørneben 45×95 | 4 | de fire 45×95-afskær (400, 400, 690, 690) | à **295** |
| Midterben 45×45 | 1 | drager-afskæret (490) | à **205** |

Hjørnebenet vender med **45 mm-fladen mod endestykket** og **95 mm-fladen mod vangen**.
Så holder de 45 mm sig fri af lamelfeltet, og de to boltakser får hver sin flade.
Midterbenet har ingen bolte, så dets orientering er ligegyldig.

Lamellerne er de eneste dele, hvor længden skal være ens til en millimeter: sæt et stop
på saven og skær alle 17 uden at flytte det. Drageren (1910) og endestykkerne (1710)
skal passe mellem hinanden — mål dem op mod rammen, før du skærer, hvis dit træ ikke er
præcis 45 mm tykt.

<div class="figrow">
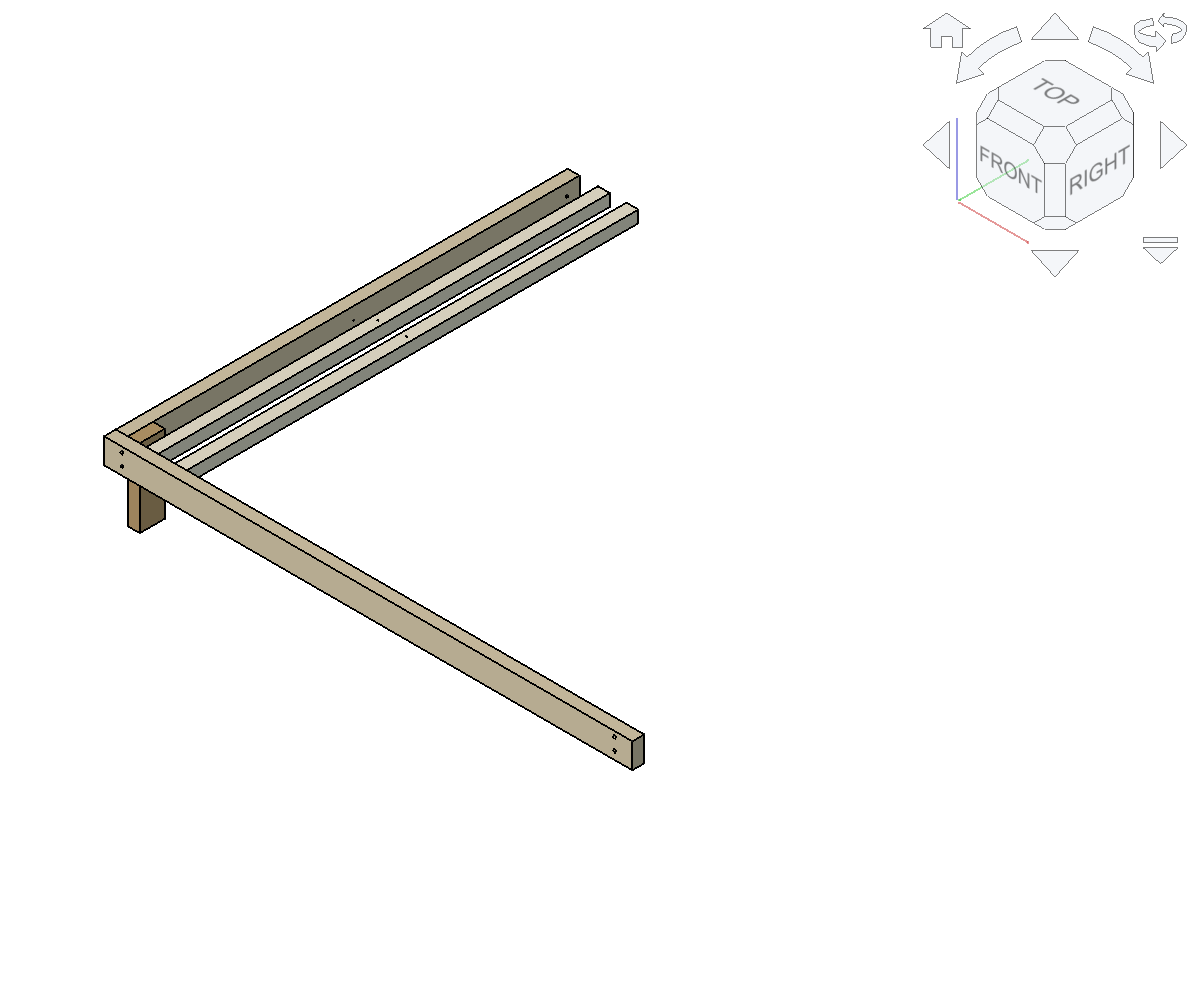
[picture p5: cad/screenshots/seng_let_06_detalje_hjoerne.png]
Hjørnedetalje
<figure><figcaption>Hjørne: vange, endestykke, ben og støtteliste</figcaption></figure>
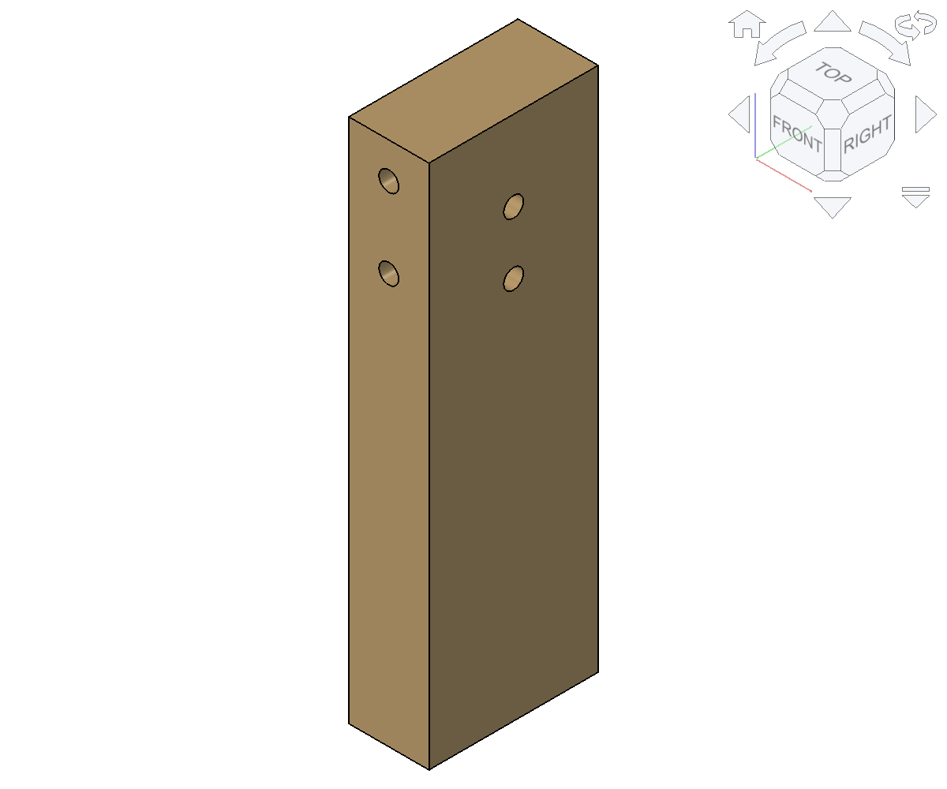
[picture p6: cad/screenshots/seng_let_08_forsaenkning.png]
Ben med bolthuller
<figure><figcaption>Hjørneben med sine 4 bolthuller</figcaption></figure>
</div>

## 5 · Boring

Princippet er det samme i alle 103 skruesamlinger: **gennemgangshul i den nære del**
(det er det, der lader skruehovedet trække delene sammen) og **pilothul i den fjerne
del**. Tommelfingerregler i fyr/gran: gennemgang = skruediameter + 0,5 mm, pilot ≈ 65 %
af skruediameteren, forsænkning Ø ≈ 2 × skruediameteren.

Del arbejdet i to: gennemgangshullerne bores på bænken, før du samler noget, og
pilothullerne bores under samlingen gennem de huller, du allerede har lavet. Så passer
de af sig selv.

### A · Bores på bænken, del for del

| Del | Antal | Huller |
|-----|---|---|
| **Støtteliste** 21×45×1770 | 2 | **34 × Ø5** lodret gennem listens 45 mm højde (lamelhullerne — mål efter arket "Boreplan · støtteliste") · **6 × Ø5** vandret gennem de 21 mm: 75 mm fra enden, derefter 330 mm c/c, midt i højden. Forsænk Ø10 i listens underside hhv. inderside |
| **Hjørneben** 45×95×295 | 4 | **2 × Ø12** gennem 95 mm-fladen (mod vangen), **230 og 275 mm** over benets fod · **2 × Ø10** gennem 45 mm-fladen (mod endestykket), **215 og 250 mm** over foden. Alle fire vinkelret — se advarslen nedenfor |
| **Vange** 45×95×2000 | 2 | **4 × Ø12** gennem de 45 mm: 67 mm fra hver ende, 30 og 75 mm over vangens underkant |
| **Endestykke** 45×95×1710 | 2 | **4 × Ø10**: 47 mm fra hver ende, 15 og 50 mm over underkanten · **2 × Ø5,5** midtfor (855 mm fra enden), 23 og 47 mm over underkanten, **forsænk Ø11 på ydersiden** |
| **Midterdrager** 45×45×1910 | 1 | **2 × Ø5,5** lodret ned, 940 og 970 mm fra én ende (= midten ±15), forsænk Ø11 i overkanten |
| **Lamel** 45×45×1710 | 17 | **1 × Ø5** lodret, 855 mm fra enden (midt), forsænk Ø10 så hovedet ender **2–3 mm under** overfladen |
| **Midterben** 45×45×205 | 1 | ingen — dets pilothuller bores under samlingen |

Bemærk de to nulpunkter: benets huller måles fra **benets fod** (den står på gulvet),
rammens fra **vangens/endestykkets underkant**. De passer sammen, fordi rammens underkant
sidder 200 mm over gulvet: 30 mm op ad vangen er de samme 230 mm op ad benet.

Bolthullerne er 2 mm større end boltene (Ø12 til M10, Ø10 til M8), fordi Ø11 og Ø9 ikke
altid kan skaffes. Slørret er en fordel her: det giver plads til, at ben og ramme bores
hver for sig. Til gengæld **bider bræddeboltens firkanthals ikke** i det store hul — hold
hovedet med en tang, når du spænder møtrikken.

### B · Bores under samlingen

| Hvor | Bor | Gennem |
|---|-----|---|
| Støtteliste → vange | Ø3 × 35 mm i vangen | listens Ø5-hul, når listen er spændt fast i højden |
| Lamelfod → støtteliste | Ø3 × 20 mm op i lamellen | listens Ø5-hul, når lamellen ligger på plads |
| Lamel → midterdrager | Ø3 (kan undværes) | lamellens Ø5-hul |
| Midterdrager → endestykke | Ø3,5 × 40 mm i dragerens endetræ | endestykkets Ø5,5-hul |
| Midterdrager → midterben | Ø3,5 × 40 mm i benets endetræ | dragerens Ø5,5-hul |
| Vinkelbeslag | Ø2,5 | beslagets egne huller |

### Forsænkning

Kegleforsænkeren er **ét bor, ikke to**: Ø16 er keglens største diameter, ikke hullets.
Du styrer diameteren med dybden, så Ø10 og Ø11 er samme bor i to dybder. 90° er vinklen
på metriske træskruehoveder (82° er til metal og passer ikke). Bor hullet **først** og
forsænk bagefter, så keglen har noget at centrere sig i. Kør 400–800 o/min med let tryk,
ellers hopper den og efterlader et trekantet hul. Prøv af på et afskær, og sæt tape på
boret i den rigtige dybde.

**23 af de 103 forsænkninger er ikke valgfri:**

- **De 17 i lamellerne** sidder i sovefladen — sænk hovedet 2–3 mm **under** overfladen,
  ikke bare plant.
- **De 4 i endestykkerne** sidder på sengens synlige yderside.
- **De 2 i dragerens overkant** ligger, hvor midterlamellen hviler. Stikker de hoveder
  1 mm op, vipper lamellen.

De øvrige 80 sidder på støttelistens under- og inderside, hvor intet ses og intet
hviler. Dér er forsænkning pænt, men ikke nødvendigt.

⚠️ **Forsænk til Ø11 for 5 × 80-skruerne.** Deres hoved er Ø10, så en Ø10-forsænkning er
lige præcis for lille til, at hovedet går plant. De 4,5-skruer har Ø9-hoved, hvor Ø10
rækker.

⚠️ **Boltkrydset i benene.** Vange- og endestykke-boltene krydser hinanden vinkelret
inde i benet med kun **15 mm lodret afstand** — altså **4 mm træ** mellem Ø12- og
Ø10-hullet. Derfor: bor vinkelret (borelære eller søjleboremaskine), og bor **alle fire
huller i et ben, før** du sætter nogen bolt i. Skævt borede huller mødes inde i benet.

⚠️ **Hullerne i støttelisten skal være Ø5, ikke Ø4.** Ø4 er et pilothul: gevindet vil
gribe i listen og jække de to dele fra hinanden i stedet for at spænde dem sammen, og
med kun ~8 mm træ til hver side flækker en 21 mm liste let langs åren. Bor lodret og
præcist.

⚠️ **De to skruer ned i midterbenet er det sted, hvor der er mindst træ.** De sidder
±15 mm fra benets midte i et 45×45 ben — altså **7,5 mm fra kanten**, i endetræ. Med
Ø5,5 er der knap 5 mm træ ud til fladen, så pilothullet er ikke valgfrit dér. Borer du i
hånden, må du gerne rykke de to huller ind til ±10 mm fra midten (12,5 mm til kanten) —
så flytter du blot dragerens gennemgangshuller tilsvarende.

⚠️ **Bor støttelisten færdig, før du skruer den på vangen.** Et af de seks vange-huller
(1725 mm fra enden) ligger kun 10,5 mm fra et lamelhul (1735,5 mm) — ca. 5,5 mm træ
mellem to Ø5-huller. Det er lettere at ramme rigtigt på en løs liste. Og de forborede
lamelhuller er selv afstands-jiggen, der placerer lamellerne senere.

**Vend begge støttelister samme vej.** Lamelhullerne ligger symmetrisk om listens midte,
men de seks vange-huller gør ikke — så begge lister skal have deres 0-ende mod samme
gavl.

## 6 · Samling

### Trin 1 · Ben på vangerne — 8 × M10 × 160

Stil en vange på højkant på gulvet og sæt et hjørneben op mod dens inderside i hver
ende:

- benets **overkant flugter med vangens overkant**
- benets ende sidder **45 mm inde** fra vangens ende (brug et 45 mm afskær som
  afstandsklods — pladsen er til endestykket)
- benets 95 mm-flade ligger mod vangen

Spænd fast med tvinger, stik boltene i **udefra**, og sæt skive + møtrik +
**kontramøtrik** på benets inderside. Hold boltehovedet med en tang, mens du spænder.
Gentag med den anden vange. Kontramøtrikken er ikke pynt: ubehandlet fyr svinder det
første år, og boltede træsamlinger løsner sig, når træet krymper.

Der stikker 20 mm bolt ud på indersiden, og skive + to møtrikker fylder 18,5 — altså
reelt plant. **Ingen forsænkning nogen steder** på denne seng.

### Trin 2 · Støttelister på vangerne — 12 × 4,5 × 50

Med vangen stadig løs er listen let at ramme. Listens **overkant skal ligge 45 mm under
vangens overkant** (= 5 mm over vangens underkant), og listen starter **115 mm inde** fra
vangens ende i begge ender. Spænd fast, bor Ø3 × 35 pilot gennem listens Ø5-huller og
skru 4,5 × 50 i.

Brug ikke 60 mm her. Det er den eneste samling, der går **vandret** gennem listens
21 mm: 21 + 45 = 66 mm stak, så en 70'er ville stikke ud på vangens yderside. 50 giver
29 mm fat i vangen og 16 mm margin.

### Trin 3 · Rammen lukkes — 8 × M8 × 100

Stil de to langsider op med benene nedad og sæt endestykkerne ind mellem dem. Endestykkets
yderside flugter med vangens ende, og dets 45 mm-flade ligger mod benet.

⚠️ **Pres hjørnet helt sammen, før møtrikken sættes på.** M8 × 100 gennem 45 + 45 = 90 mm
efterlader kun 10 mm gevind, og møtrik + Ø24-skive bruger 8,5 af dem. Er der 2 mm luft i
hjørnet, når møtrikken ikke gevindet. Derfor også: **ingen kontramøtrik og ingen nyloc på
denne akse** — en M8 nyloc er ~8 mm høj og løber tør for gevind. Spænd vange-boltene
efter, så hjørnet er lukket, inden du går videre.

Rammen er nu en stiv kasse. Kontrollér diagonalerne (hjørne til hjørne skal måle ens),
før du fortsætter.

### Trin 4 · Midterdrager og midterben — 4 + 2 × 5 × 80 og 2 vinkelbeslag

Drageren på 1910 mm passer præcis mellem endestykkerne. Dens **overkant skal flugte med
støttelisternes overkant** (45 mm under rammens overkant) — så ligger lamellerne plant på
alle tre understøtninger. Understøt den midlertidigt i midten, spænd enderne fast, bor
Ø3,5 × 40 pilot gennem endestykkets to Ø5,5-huller ind i dragerens endetræ, og skru
5 × 80 i.

Endetræ alene er en svag samling, så hver ende får desuden et **vinkelbeslag**. Montér
det på **siden** af drageren, ikke over eller under — ellers koster det frihøjde. Brug de
fire Ø5-huller i hver vinge med beslagskruer (fladt hoved, Ø2,5 pilot). Vil du følge
Simpsons anbefaling helt, køb 4 beslag og sæt et i hver side af drageren.

Sæt til sidst **midterbenet** under drageren på midten. Dets 205 mm er præcis frihøjden,
så drageren løfter sig ikke: bor Ø3,5 × 40 ned gennem dragerens to Ø5,5-huller i benets
endetræ og skru to 5 × 80 lodret ned ovenfra. De seks 80 mm-skruer er de eneste, der går
i endetræ, hvor holdeevnen kun er 50–75 % af sidetræs — derfor 35 mm fat i stedet for 15.

### Trin 5 · Lamellerne — 68 + 17 × 4,5 × 60

Lamellerne skrues **nedefra og op**, så der ikke kommer skruehoveder i sovefladen. Sæt
derfor sengen op på to bukke, kasser eller stole, så du kan komme til med maskinen
nedefra. Skruerne sidder kun ~56 mm inde fra sengens yderkant, så du skal ikke ind under
midten. (Har du en kort eller vinklet skruemaskine, kan det gøres i de 200 mm frihøjde,
men det er trangt.)

1. Læg lamellerne på plads: to ender på støttelisterne, midten på drageren.
2. Centrér hver lamel over sit hulpar i listen. Hullerne sidder 24 mm fra hinanden,
   centreret på lamellens 45 mm fod — **de forborede huller er selv afstands-jiggen**, så
   når lamellen dækker sit par symmetrisk, sidder den rigtigt. Afstanden bliver
   107,8 mm c/c og spalten ~63 mm.
3. **Nedefra:** bor Ø3 × 20 mm op i lamellen gennem listens Ø5-hul, og skru en 4,5 × 60
   i. Hullet i listen er 45 mm dybt, så skruen får 15 mm fat i lamellen og bryder ikke ud
   i sovefladen. To skruer i hver ende, 68 i alt.
4. **Oppefra:** én 4,5 × 60 ned gennem lamellens forborede midterhul i drageren. Hovedet
   skal 2–3 mm under overfladen.

Begge lamelsamlinger *hviler* — lamellen bærer sin last på listen og drageren, så
skruerne er ren lås. Derfor er 15 mm fat rigeligt.

<div class="figrow one">
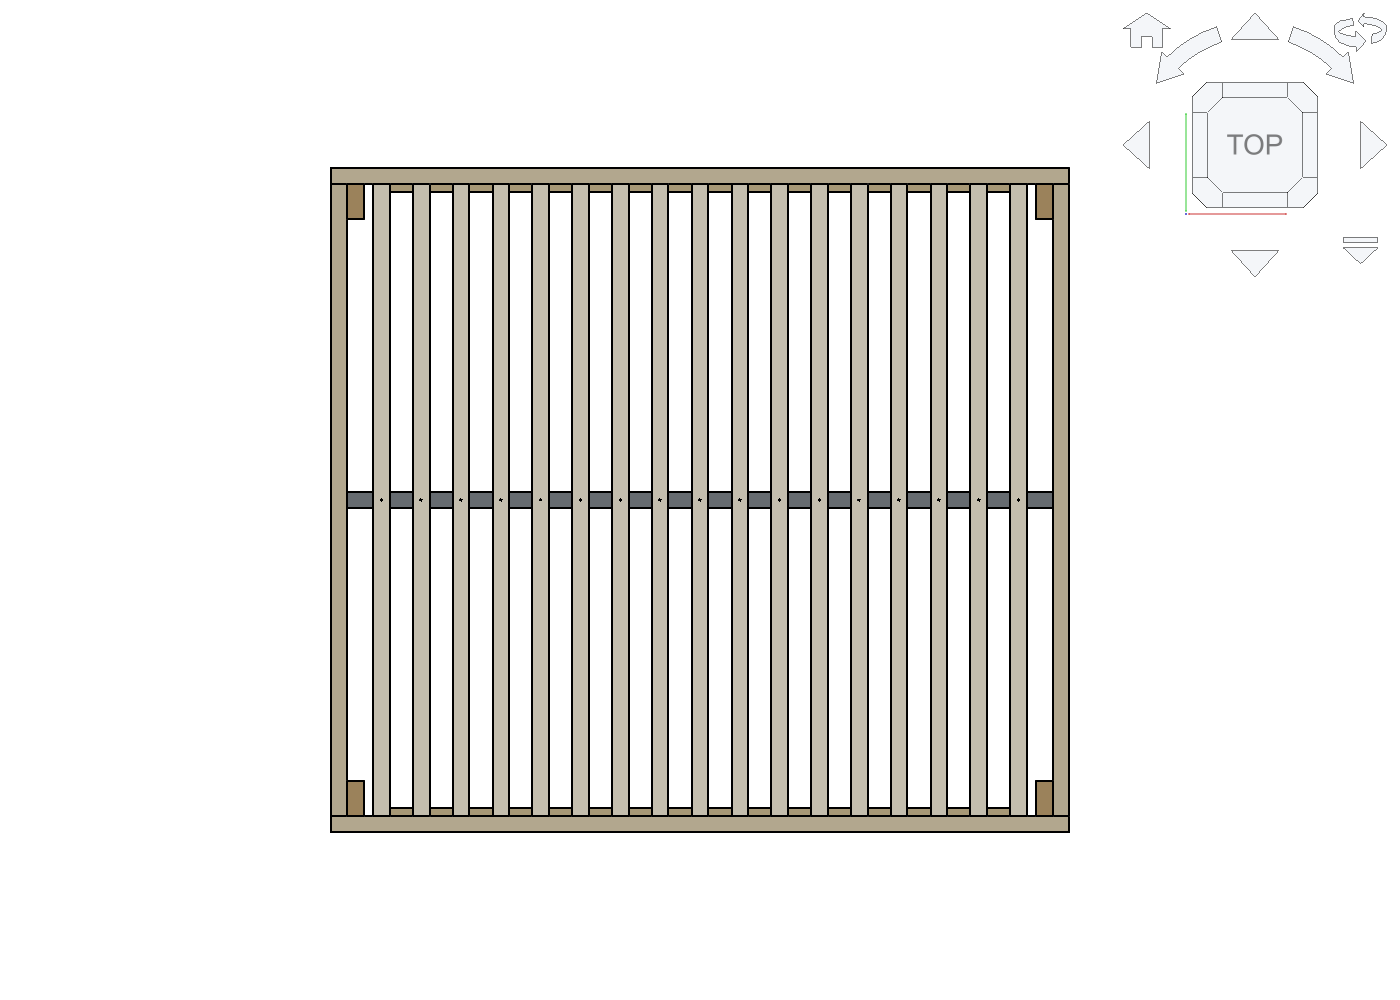
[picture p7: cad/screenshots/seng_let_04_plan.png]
Plan
<figure><figcaption>Færdigt lamelfelt set ovenfra — 17 lameller, c/c 107,8 mm</figcaption></figure>
</div>

### Trin 6 · Kontrol og efterspænding

- **Står den plant?** Vipper sengen, sæt en tynd skive under det ene ben eller slib
  1 mm af. Gulvet er sjældent plant, og benene er af afskær.
- **Kør en hånd over lamellerne.** Intet skruehoved må rage op — det er det, madrassen
  og betrækket ligger på.
- **Slib kanterne let** på ramme og lameller med sandpapir 120. Det sparer futonens
  betræk.
- **Efterspænd de 8 M10-bolte** efter 2–4 uger og igen efter en fyringssæson. Ubehandlet
  fyr svinder, og det er derfor kontramøtrikkerne sidder der.
- Sengen er tænkt ubehandlet. Vil du olie eller sæbebehandle den, gør det **før**
  samling, mens delene er løse.

## 7 · Holder det til to personer? {: .newpage }

Kort statik-tjek for fyr (E ≈ 10 GPa), regnet på den byggede geometri. Grænsen L/300 er
den normale komfortgrænse for en sengebund:

| Del | Frit spænd | Nedbøjning ved fuld last | Grænse L/300 |
|-----|---|---|---|
| Lamel 45 × 45 | 810 mm | ~1,7 mm (50 kg punktlast midt på ét fag) | 2,7 mm |
| Midterdrager 45 × 45 | 2 fag à 955 mm | ~3–4 mm pr. fag | ~3,2 mm |
| Vange 45 × 95 | 1910 mm | 1–2 mm | ~6,4 mm |

Lamellerne er kontinuerte over drageren, hvilket gør dem stivere endnu, og et kvadratisk
tværsnit (slankhed 1:1) kan ikke vælte — domino-problemet fra høje, tynde lameller
findes ikke her.

**Drageren er et grænsetilfælde** lige omkring L/300. Uproblematisk under en eftergivende
futon, men vil du have mere margin: sæt drageren på højkant som 45 × 70 — så falder
frihøjden under midten fra 205 til 180 mm, altså under de 20 cm — eller sæt et midterben
mere i, hvilket ikke koster frihøjde.

**Boltene er kraftigt overdimensionerede.** Belastningen er ~2,3 kN fordelt på fire
hjørner, altså ~600 N pr. hjørne på to bolte. Grænsen sættes ikke af bolten (en M8 kan
~8,8 kN i forskydning) men af træets hulrandstyrke: 8 mm × 45 mm × ~25 MPa ≈ 9 kN — 15
gange over behovet. Derfor er M8 rigeligt på endestykke-aksen, og derfor betyder de 2 mm
op til M10 ingenting. Det, der betyder noget, er skivens størrelse.

### Vil du ændre noget?

- **Færre lameller:** 16 stk. sparer ~1,7 kg og giver ~71 mm spalte — fint i den brede
  ende for en blød futon. Både lamellængder og støttelistens hulmønster skal så regnes om.
- **Stivere midte:** et ekstra midterben er den billige vej — det koster ét hul og ingen
  frihøjde. En 45 × 70-drager på højkant er stivere endnu, men efterlader kun 180 mm under
  midten.
- **Anden madras:** rammen er madrasmålet. Ændrer du det, ændrer vanger (2000),
  endestykker/lameller (1710) og drager (1910) sig alle sammen.

### Forbehold

- **Pris:** træet er prischecket til 1.376,40 kr hos Silvan og vange-boltene til
  159,80 kr hos jem&fix (juli 2026). Skruer og beslag er fire pakker, som ikke er
  prischecket — regn med ~1.650 kr i alt. 45×45-lameller er dyre pr. bræt, men benene er
  gratis.
- **Ben af afskær:** ben-tværsnittet er 45 × 95, hvilket er slankt for et sengeben. Det
  holder, fordi rammen er en stiv boltet kasse, så benene står i ren tryk. Valget er også
  praktisk: der fandtes ingen firkantet, ubehandlet stolpe hos jem&fix, Silvan eller
  Bauhaus — alle massive stolper er trykimprægnerede eller malede.
- **Lamelspalte ~63 mm** og åbningsareal ~58 %. God udluftning nedefra og uproblematisk
  for en futon; til en tynd madras uden futon-fylde ville man vælge tættere lameller.

## 8 · Tegninger {: .newpage }

De fire ark bagest er målsatte og hører til hvert sit trin:

| Ark | Brug det til |
|-----|---|
| Tegning — mål, plan og opstalt | overblik og kontrolmål (afsnit 1 og 4) |
| Boreplan — bolte og skruer | benene, vangerne og endestykkerne (afsnit 5 A) |
| Boreplan — støttelistens lamelhuller | alle 34 hulafstande, målt fra listens ene ende |
| Boreplan — midterdrager → endestykke | vinkelbeslagets placering (trin 4) |

**Mål alle 34 lamelhuller fra samme ende med båndmål** — step ikke 107,8 mm 16 gange, så
hober fejlen sig op. Kontrolmål: første hul 10,5 mm inde, sidste 10,5 mm fra den anden
ende, midterste lamel præcis på 885 mm.

<div class="colophon">
Model, tegninger og boreplaner er genereret fra en parametrisk FreeCAD-model
(<code>scripts/build_bed_let.py</code> → <code>cad/seng_let.FCStd</code>). Alle mål i
vejledningen er hentet fra den byggede model. Ændrer du dimensioner eller lamelantal,
skal tegninger og boreplaner genereres om.
</div>

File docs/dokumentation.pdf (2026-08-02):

# Sengebund til futon 180 × 200 cm

Byggevejledning · ubehandlet fyr/gran · ben af afskær

Let, ubehandlet futon-sengebund i fyr/gran: slank 45×95-ramme boltet i hjørnerne, 17 kvadratiske 45×45-lameller der flugter med rammens overkant, og en langsgående midterdrager på ét midterben, der halverer lamelspændet. Udvendige mål er madrasmålet, så madrassen ligger plant af med kanten — ingen liste op om.
Ingen lim, ingen trykimprægneret træ og ingen avanceret træbearbejdning: alle snit er lige, og alle samlinger er skruet eller boltet. Benene skæres af afskærene, så du køber intet træ til dem.

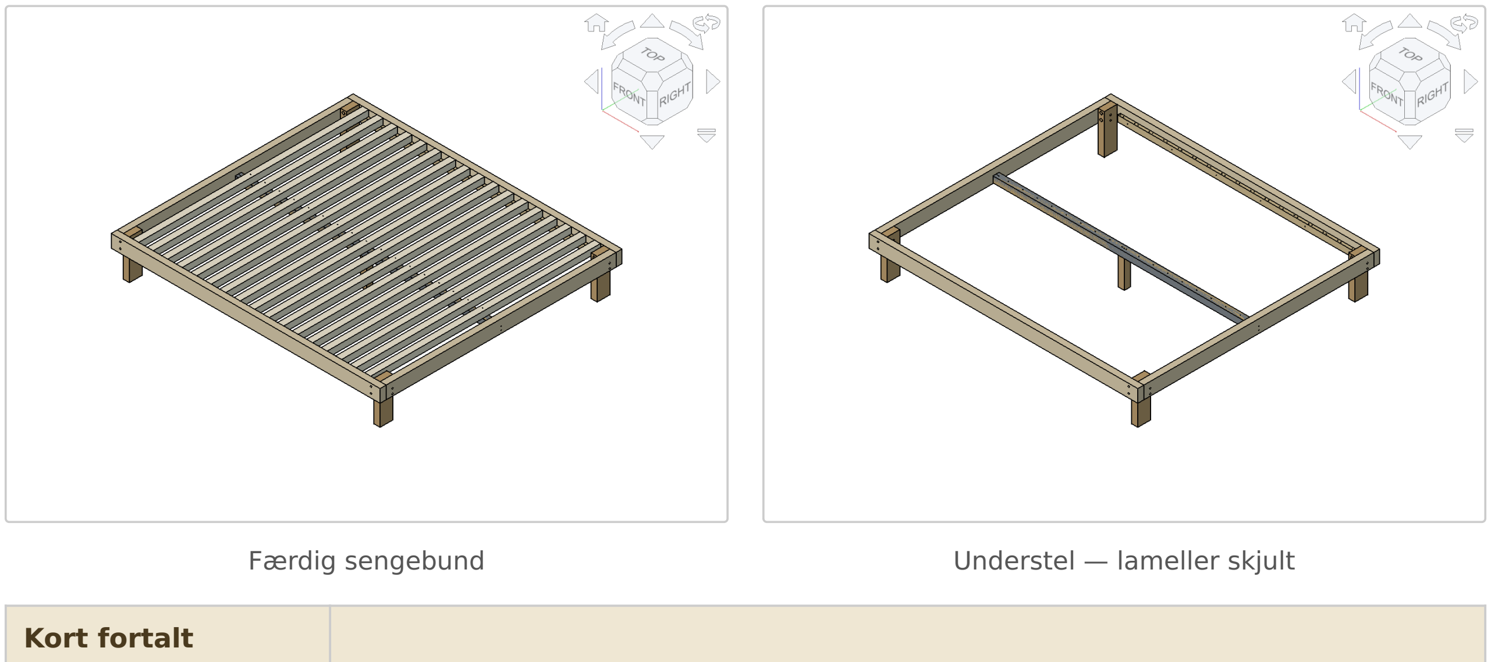
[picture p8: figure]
Færdig sengebund; Understel — lameller skjult; Kort fortalt

Udvendige mål | 1800 × 2000 mm (= madrassen, flush)
Sovehøjde | 295 mm bund + 15–18 cm futon ≈ 45 cm
Frihøjde til gulv | 200 mm under rammen, 205 mm under drageren
Vægt | ~48 kg
Træ | 22 reglar + 2 forskallingsbrædder, ubehandlet fyr/gran
Fastgørelse | 103 skruer i tre længder + 16 gennemgående bolte + 2 vinkelbeslag
Pris | ~1.650 kr (juli 2026)
Sværeste opgave | de 8+8 bolthuller i benene — de skal bores vinkelret

Rækkefølgen i vejledningen er arbejdsrækkefølgen: indkøb → værktøj → skæreplan → boring → samling → kontrol. Bagest ligger fire målsatte tegninger og et statik-tjek. Boringen er det store stykke arbejde (103 huller plus forsænkninger); samlingen går hurtigt, når hullerne sidder.

Sengebund til futon 180 × 200 cm · side 1 / 16

## 1 · Sådan er sengen bygget

← 200 cm (længde) →
┌────────────────────────────┐ | ┐
│ ▪ ▪ ▪ ▪ ▪ ▪ ▪ ▪ ▪ ▪ │ | │ ← 45×45 lameller (17 stk)
│ ═══════ midterdrager ══════ │ | │ | spænder tværs, hviler på
│ ▪ ▪ ▪ ▪ ▪ ▪ ▪ ▪ ▪ ▪ │ | │ | 3 punkter: liste-drager-liste
└────────────────────────────┘ | ┘ 180 cm (bredde)
▙ | ▪ | ▟
ben | midterben | ben

To vanger 45×95 + to endestykker boltes sammen om 4 hjørneben = en stiv kasse. Støttelister 21×45 skrues på vangernes indersider og bærer lamelenderne.
Midterdrageren 45×45 løber i længderetningen på ét midterben og halverer lamellernes frie spænd fra 1710 mm til ~810 mm.
Lamellerne 45×45 flugter med rammens overkant. Det halverede spænd gør den lille kvadratiske profil stiv nok, og et kvadratisk tværsnit kan ikke vælte. Madrassen hviler plant på ramme og lameller i samme kote.

Højder (alle mål fra gulv)

top af lameller = top af ramme 295 mm ┄┄┄┄ sovefladen (lameller flugter med rammen)
lamel-underkant | 250 mm ─────┐
støtteliste-overkant | 250 mm | │ vange 95 mm
underkant ramme | 200 mm ─────┘ ← 20 cm FRIHØJDE
underkant drager (45×45) | 205 mm ───── | ← 5 mm over rammens underkant
gulv | 0 mm ▂▂▂▂▂▂

Hjørnebenene er derfor 295 mm (200 + 95) og midterbenet 205 mm. Frihøjden er 200 mm under rammen og 205 mm under drageren, så en robotstøvsuger på 20 cm går fri overalt — også under

•
•
•

•

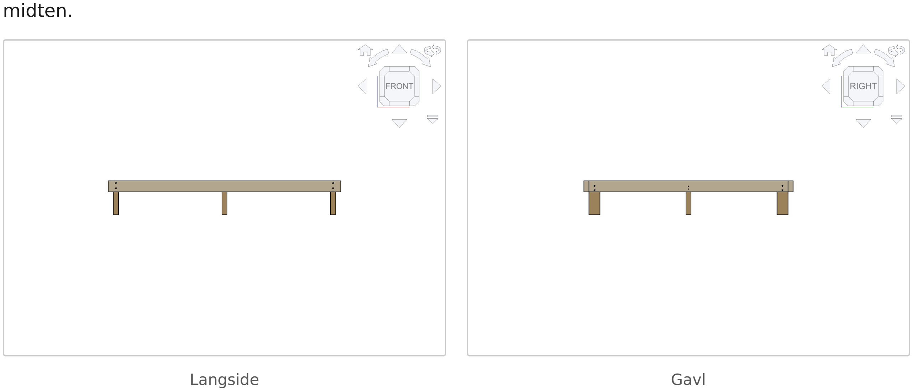
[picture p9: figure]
midten.; Langside; Gavl

## 2 · Indkøb

Træ (fyr/gran, ubehandlet, høvlet)

Vare | Antal | Pris/stk | I alt | Bruges til
Reglar 45×45×2400 ubeh. | 18 | 64,80 | 1.166,40 | 17 lameller + 1 midterdrager
Reglar 45×95×2400 ubeh. | 4 | 43,80 | 175,20 | 2 vanger + 2 endestykker
Forskalling 21×45×2400 ubeh. | 2 | 17,40 | 34,80 | 2 støttelister
Ben (4 hjørne + 1 midter) | 0 | — | 0 | skæres af afskærene

Træ i alt 1.376,40 kr (Silvan, juli 2026, ekskl. levering). Der er kun to reglar-tværsnit at holde styr på: 45×45 til lameller og drager, 45×95 til rammen.

Vælg træ, der er lige — især de fire 45×95

Reglar er en byggevare, ikke en møbelvare, og bunken i byggemarkedet er blandet. Sortér selv, og læg de dårlige tilbage. Sigt langs hvert bræt fra enden — først på fladen, så på højkant — og drej det derefter om sin egen akse. Læg det på et plant gulv og se, om det vipper på diagonalen.
Vrid (snoning) — enderne er drejet i forhold til hinanden. Den værste fejl her, og den eneste, du ikke kan skrue væk.
Svaj — buet på højkant, "banan". Giver en ramme, hvis diagonaler ikke vil passe.
Krumning — buet på fladen. Til at leve med; skruerne trækker en mindre bue ud.
Skålning — hulning på tværs. Uden betydning i disse tværsnit.
Det er de fire 45×95 til vanger og endestykker, det gælder. De sætter rammens geometri, og et vrid dér forplanter sig gennem hele sengen: hjørnerne kommer skævt sammen, benene hælder en anelse, og støttelistens overkant følger vangens vrid, så lamelfladen ikke bliver helt plan. Sengen holder fint — de boltede hjørner er stærke nok til at tvinge træet på plads — men vridet kan ses. 45×45-lamellerne er mere tilgivende: de er understøttet tre steder og skruet fast i begge ender, så en let bue rettes ud af samlingen.
Et roligt bræt kendes på, at årerne løber nogenlunde parallelt med kanten, at marven (den bløde kerne, der ses som tætte cirkelbuer i endetræet) ikke er med i brættet, og at det føles tørt og let. Marvholdt eller fugtigt træ vrider sig, når det tørrer — også efter sengen er bygget. Husk også, at benene skæres af afskærene: et vridt endestykke giver et vridt ben. Lad træet ligge en uges tid indendørs, hvor sengen skal stå, stablet plant og med luft omkring, før du skærer op — så sker det meste af bevægelsen, inden delene er i mål.

•

•
•
•

Skruer, bolte og beslag

Vare | Køb | Bruges
Spånskrue 4,5 × 60 (fx Simpson TTZNFS, art. 74485) | 200-pak | 85
Spånskrue 4,5 × 50 (art. 74484) | 200-pak | 12
Spånskrue 5,0 × 80 (art. 76540) | 100-pak | 6
Beslagskrue 4,0 × 20, fladt hoved (Simpson TTUFP, art. 74519) | 200-pak | 16
Bræddebolt M10 × 160 DIN 603 (jem&fix, NKT) | 4 × 2-pak à 39,95 = 159,80 kr | 8
Løse M10-møtrikker til kontramøtrik | 8 stk (~25 kr) | 8
Spændeskive M10, 10,5 × 30 × 2,5 | 15-pak | 8
Bræddebolt M8 × 100 m/ møtrik | 12-pak | 8
Spændeskive M8, 8,4 × 24 × 2,0 | 30-pak | 8
Vinkelbeslag Simpson AC35350 | 2 stk | 2

Alle skruer skal være spånskruer med undersænket hoved, Torx og delgevind. Elforzinket rækker fint indendørs; rustfri er kun nødvendigt udendørs. Beslagskruerne er undtagelsen — de skal have fladt hoved, for en undersænket skrue trækker sig ned i beslagets hul og kan flække det.
Pakkestørrelserne giver rigeligt overskud. Det var det billigste: skruerne findes ikke i mindre pakker i de længder.
Køb M10 × 160 til vangerne — ikke M10 × 140. Vange-aksen går gennem 45 + 95 = 140 mm træ, så en 140 mm bolt ender præcis plant med træet og har nul gevind tilbage til møtrikken. 160 mm giver de 20 mm, der skal til skive + møtrik + kontramøtrik. jem&fix har dem kun i 2-pak, og der findes intet mellem 140 og 160 (en M10 × 200 ville stritte 60 mm ud).
Skiverne skal være store. En almindelig M8-planskive er kun Ø16 og trækker sig ind i træet — derfor Ø24 på endestykke-aksen. Skiven gør mere for samlingen end boltdiameteren.

## 3 · Værktøj og bor

Kap-/geringssav eller rundsav med anslag — 23 lige snit, ingen geringer Søjleboremaskine eller borelære — nødvendig til benenes bolthuller, se advarslen om boltkrydset i afsnit 5
Boremaskine + skruemaskine med Torx-bit (størrelsen står på skruepakken)
Bor: Ø2,5 · Ø3 · Ø3,5 · Ø5 · Ø5,5 · Ø10 · Ø12
Ø10 og Ø12 skal være lange bor: de går gennem 90 hhv. 140 mm træ i én gennemgang. Et almindeligt 100 mm-spiralbor rækker ikke — brug et slangebor eller et langt spiralbor med mindst 160 mm nyttelængde
Én kegleforsænker 90°, Ø16, HSS, sekskantskaft (~60–100 kr)
Fastnøgle/top 13 mm (M8) og 17 mm (M10) + en tang til at holde boltehovedet
Båndmål (5 m), vinkel, blyant, mindst 4 skruetvinger, malertape (til at markere boredybde), sandpapir 120

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
To bukke, kasser eller stole at sætte sengen op på, når lamellerne skal skrues fast nedefra Køb ikke et kombineret undersænkbor. Det borer forhul og forsænker i én bevægelse med én diameter — men her skal den nære del have Ø5 gennemgang og den fjerne Ø3 pilot, altså to diametre i samme hul. En løs kegleforsænker er den rigtige.

## 4 · Skæreplan

Skær alt op først, og mærk afskærene op med det samme — de fem ben kommer af dem.

Emne | Køb | Skæres til | Afskær
Lameller | 17 × 45×45×2400 | 1 à 1710 pr. stk | 17 × 690 (overskud)
Midterdrager | 1 × 45×45×2400 | 1 à 1910 | 1 × 45×45×490 → midterben
Vanger | 2 × 45×95×2400 | à 2000 | 2 × 45×95×400 → hjørneben
Endestykker | 2 × 45×95×2400 | à 1710 | 2 × 45×95×690 → hjørneben
Støttelister | 2 × 21×45×2400 | à 1770 | 2 × 630 (overskud)
Ben af afskær (køb intet nyt træ | )
Ben | Antal | Skæres af | Længde
Hjørneben 45×95 | 4 | de fire 45×95-afskær (400, 400, 690, 690) | à 295
Midterben 45×45 | 1 | drager-afskæret (490) | à 205

Hjørnebenet vender med 45 mm-fladen mod endestykket og 95 mm-fladen mod vangen. Så holder de 45 mm sig fri af lamelfeltet, og de to boltakser får hver sin flade. Midterbenet har ingen bolte, så dets orientering er ligegyldig.
Lamellerne er de eneste dele, hvor længden skal være ens til en millimeter: sæt et stop på saven og skær alle 17 uden at flytte det. Drageren (1910) og endestykkerne (1710) skal passe mellem hinanden — mål dem op mod rammen, før du skærer, hvis dit træ ikke er præcis 45 mm tykt.

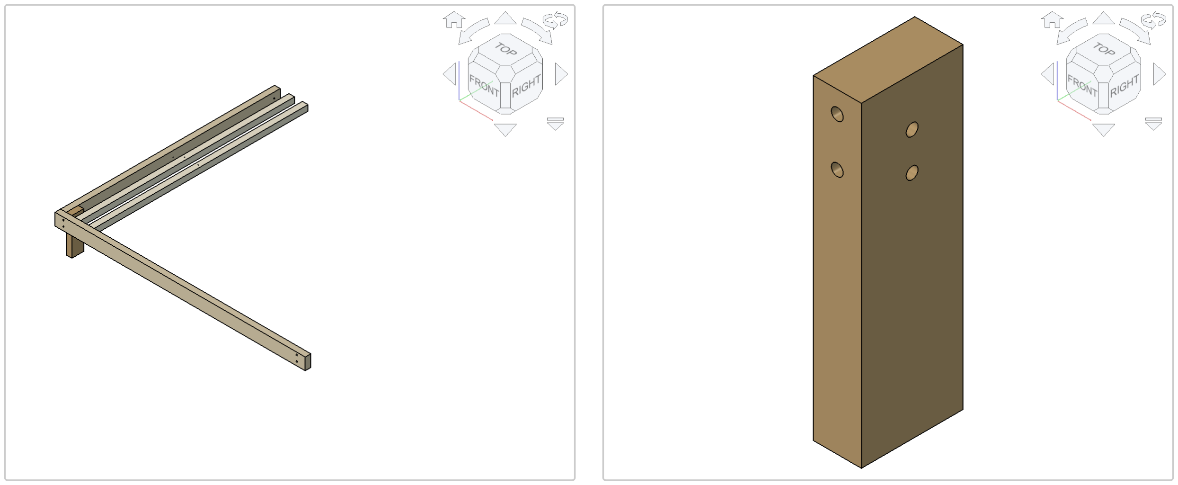
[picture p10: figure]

Hjørne: vange, endestykke, ben og støtteliste | Hjørneben med sine 4 bolthuller

•

## 5 · Boring

Princippet er det samme i alle 103 skruesamlinger: gennemgangshul i den nære del (det er det, der lader skruehovedet trække delene sammen) og pilothul i den fjerne del. Tommelfingerregler i fyr/gran: gennemgang = skruediameter + 0,5 mm, pilot ≈ 65 % af skruediameteren, forsænkning Ø ≈ 2 × skruediameteren.
Del arbejdet i to: gennemgangshullerne bores på bænken, før du samler noget, og pilothullerne bores under samlingen gennem de huller, du allerede har lavet. Så passer de af sig selv.

A · Bores på bænken, del for del

Del | Antal | Huller
Støtteliste 21×45×1770 | 2 | 34 × Ø5 lodret gennem listens 45 mm højde (lamelhullerne — mål efter arket "Boreplan · støtteliste") · 6 × Ø5 vandret gennem de 21 mm: 75 mm fra enden, derefter 330 mm c/c, midt i højden. Forsænk Ø10 i listens underside hhv. inderside
Hjørneben 45×95×295 | 4 | 2 × Ø12 gennem 95 mm-fladen (mod vangen), 230 og 275 mm over benets fod · 2 × Ø10 gennem 45 mm-fladen (mod endestykket), 215 og 250 mm over foden. Alle fire vinkelret — se advarslen nedenfor
Vange 45×95×2000 | 2 | 4 × Ø12 gennem de 45 mm: 67 mm fra hver ende, 30 og 75 mm over vangens underkant
Endestykke 45×95×1710 | 2 | 4 × Ø10: 47 mm fra hver ende, 15 og 50 mm over underkanten · 2 × Ø5,5 midtfor (855 mm fra enden), 23 og 47 mm over underkanten, forsænk Ø11 på ydersiden
Midterdrager 45×45×1910 | 1 | 2 × Ø5,5 lodret ned, 940 og 970 mm fra én ende (= midten ±15), forsænk Ø11 i overkanten
Lamel 45×45×1710 | 17 | 1 × Ø5 lodret, 855 mm fra enden (midt), forsænk Ø10 så hovedet ender 2–3 mm under overfladen
Midterben 45×45×205 | 1 | ingen — dets pilothuller bores under samlingen

Bemærk de to nulpunkter: benets huller måles fra benets fod (den står på gulvet), rammens fra vangens/endestykkets underkant. De passer sammen, fordi rammens underkant sidder 200 mm over gulvet: 30 mm op ad vangen er de samme 230 mm op ad benet.
Bolthullerne er 2 mm større end boltene (Ø12 til M10, Ø10 til M8), fordi Ø11 og Ø9 ikke altid kan skaffes. Slørret er en fordel her: det giver plads til, at ben og ramme bores hver for sig. Til gengæld bider bræddeboltens firkanthals ikke i det store hul — hold hovedet med en tang, når du spænder møtrikken.

B · Bores under samlingen

Hvor | Bor | Gennem
Støtteliste → vange | Ø3 × 35 mm i vangen | listens Ø5-hul, når listen er spændt fast i højden
Lamelfod → støtteliste | Ø3 × 20 mm op i lamellen | listens Ø5-hul, når lamellen ligger på plads
Lamel → midterdrager | Ø3 (kan undværes) | lamellens Ø5-hul
Midterdrager → endestykke | Ø3,5 × 40 mm i dragerens endetræ | endestykkets Ø5,5-hul
Midterdrager → midterben | Ø3,5 × 40 mm i benets endetræ | dragerens Ø5,5-hul
Vinkelbeslag | Ø2,5 | beslagets egne huller

Forsænkning

Kegleforsænkeren er ét bor, ikke to: Ø16 er keglens største diameter, ikke hullets. Du styrer diameteren med dybden, så Ø10 og Ø11 er samme bor i to dybder. 90° er vinklen på metriske træskruehoveder (82° er til metal og passer ikke). Bor hullet først og forsænk bagefter, så keglen har noget at centrere sig i. Kør 400–800 o/min med let tryk, ellers hopper den og efterlader et trekantet hul. Prøv af på et afskær, og sæt tape på boret i den rigtige dybde.

### 23 af de 103 forsænkninger er ikke valgfri:

De 17 i lamellerne sidder i sovefladen — sænk hovedet 2–3 mm under overfladen, ikke bare plant.
De 4 i endestykkerne sidder på sengens synlige yderside.
De 2 i dragerens overkant ligger, hvor midterlamellen hviler. Stikker de hoveder 1 mm op, vipper lamellen.
De øvrige 80 sidder på støttelistens under- og inderside, hvor intet ses og intet hviler. Dér er forsænkning pænt, men ikke nødvendigt.
Forsænk til Ø11 for 5 × 80-skruerne. Deres hoved er Ø10, så en Ø10-forsænkning er lige præcis for lille til, at hovedet går plant. De 4,5-skruer har Ø9-hoved, hvor Ø10 rækker. Boltkrydset i benene. Vange- og endestykke-boltene krydser hinanden vinkelret inde i benet med kun 15 mm lodret afstand — altså 4 mm træ mellem Ø12- og Ø10-hullet. Derfor: bor vinkelret (borelære eller søjleboremaskine), og bor alle fire huller i et ben, før du sætter nogen bolt i. Skævt borede huller mødes inde i benet.
Hullerne i støttelisten skal være Ø5, ikke Ø4. Ø4 er et pilothul: gevindet vil gribe i listen og jække de to dele fra hinanden i stedet for at spænde dem sammen, og med kun ~8 mm træ til hver side flækker en 21 mm liste let langs åren. Bor lodret og præcist.
De to skruer ned i midterbenet er det sted, hvor der er mindst træ. De sidder ±15 mm fra benets midte i et 45×45 ben — altså 7,5 mm fra kanten, i endetræ. Med Ø5,5 er der knap 5 mm træ ud til fladen, så pilothullet er ikke valgfrit dér. Borer du i hånden, må du gerne rykke de to huller ind til ±10 mm fra midten (12,5 mm til kanten) — så flytter du blot dragerens gennemgangshuller tilsvarende.
Bor støttelisten færdig, før du skruer den på vangen. Et af de seks vange-huller (1725 mm fra enden) ligger kun 10,5 mm fra et lamelhul (1735,5 mm) — ca. 5,5 mm træ mellem to Ø5-

•

•
•

huller. Det er lettere at ramme rigtigt på en løs liste. Og de forborede lamelhuller er selv afstands-jiggen, der placerer lamellerne senere.
Vend begge støttelister samme vej. Lamelhullerne ligger symmetrisk om listens midte, men de seks vange-huller gør ikke — så begge lister skal have deres 0-ende mod samme gavl.

## 6 · Samling

Trin 1 · Ben på vangerne — 8 × M10 × 160

Stil en vange på højkant på gulvet og sæt et hjørneben op mod dens inderside i hver ende: benets overkant flugter med vangens overkant
benets ende sidder 45 mm inde fra vangens ende (brug et 45 mm afskær som afstandsklods — pladsen er til endestykket)
benets 95 mm-flade ligger mod vangen
Spænd fast med tvinger, stik boltene i udefra, og sæt skive + møtrik + kontramøtrik på benets inderside. Hold boltehovedet med en tang, mens du spænder. Gentag med den anden vange. Kontramøtrikken er ikke pynt: ubehandlet fyr svinder det første år, og boltede træsamlinger løsner sig, når træet krymper.
Der stikker 20 mm bolt ud på indersiden, og skive + to møtrikker fylder 18,5 — altså reelt plant. Ingen forsænkning nogen steder på denne seng.

Trin 2 · Støttelister på vangerne — 12 × 4,5 × 50

Med vangen stadig løs er listen let at ramme. Listens overkant skal ligge 45 mm under vangens overkant (= 5 mm over vangens underkant), og listen starter 115 mm inde fra vangens ende i begge ender. Spænd fast, bor Ø3 × 35 pilot gennem listens Ø5-huller og skru 4,5 × 50 i.
Brug ikke 60 mm her. Det er den eneste samling, der går vandret gennem listens 21 mm: 21 + 45 = 66 mm stak, så en 70'er ville stikke ud på vangens yderside. 50 giver 29 mm fat i vangen og 16 mm margin.

Trin 3 · Rammen lukkes — 8 × M8 × 100

Stil de to langsider op med benene nedad og sæt endestykkerne ind mellem dem. Endestykkets yderside flugter med vangens ende, og dets 45 mm-flade ligger mod benet.
Pres hjørnet helt sammen, før møtrikken sættes på. M8 × 100 gennem 45 + 45 = 90 mm efterlader kun 10 mm gevind, og møtrik + Ø24-skive bruger 8,5 af dem. Er der 2 mm luft i hjørnet, når møtrikken ikke gevindet. Derfor også: ingen kontramøtrik og ingen nyloc på denne akse — en M8 nyloc er ~8 mm høj og løber tør for gevind. Spænd vange-boltene efter, så hjørnet er lukket, inden du går videre.
Rammen er nu en stiv kasse. Kontrollér diagonalerne (hjørne til hjørne skal måle ens), før du fortsætter.

Trin 4 · Midterdrager og midterben — 4 + 2 × 5 × 80 og 2 vinkelbeslag

Drageren på 1910 mm passer præcis mellem endestykkerne. Dens overkant skal flugte med støttelisternes overkant (45 mm under rammens overkant) — så ligger lamellerne plant på alle tre understøtninger. Understøt den midlertidigt i midten, spænd enderne fast, bor Ø3,5 × 40 pilot gennem endestykkets to Ø5,5-huller ind i dragerens endetræ, og skru 5 × 80 i.

•
•

•

Endetræ alene er en svag samling, så hver ende får desuden et vinkelbeslag. Montér det på siden af drageren, ikke over eller under — ellers koster det frihøjde. Brug de fire Ø5-huller i hver vinge med beslagskruer (fladt hoved, Ø2,5 pilot). Vil du følge Simpsons anbefaling helt, køb 4 beslag og sæt et i hver side af drageren.
Sæt til sidst midterbenet under drageren på midten. Dets 205 mm er præcis frihøjden, så drageren løfter sig ikke: bor Ø3,5 × 40 ned gennem dragerens to Ø5,5-huller i benets endetræ og skru to 5 × 80 lodret ned ovenfra. De seks 80 mm-skruer er de eneste, der går i endetræ, hvor holdeevnen kun er 50–75 % af sidetræs — derfor 35 mm fat i stedet for 15.

Trin 5 · Lamellerne — 68 + 17 × 4,5 × 60

Lamellerne skrues nedefra og op, så der ikke kommer skruehoveder i sovefladen. Sæt derfor sengen op på to bukke, kasser eller stole, så du kan komme til med maskinen nedefra. Skruerne sidder kun ~56 mm inde fra sengens yderkant, så du skal ikke ind under midten. (Har du en kort eller vinklet skruemaskine, kan det gøres i de 200 mm frihøjde, men det er trangt.)
Læg lamellerne på plads: to ender på støttelisterne, midten på drageren.
Centrér hver lamel over sit hulpar i listen. Hullerne sidder 24 mm fra hinanden, centreret på lamellens 45 mm fod — de forborede huller er selv afstands-jiggen, så når lamellen dækker sit par symmetrisk, sidder den rigtigt. Afstanden bliver 107,8 mm c/c og spalten ~63 mm.
Nedefra: bor Ø3 × 20 mm op i lamellen gennem listens Ø5-hul, og skru en 4,5 × 60 i. Hullet i listen er 45 mm dybt, så skruen får 15 mm fat i lamellen og bryder ikke ud i sovefladen. To skruer i hver ende, 68 i alt.
Oppefra: én 4,5 × 60 ned gennem lamellens forborede midterhul i drageren. Hovedet skal 2–3 mm under overfladen.
Begge lamelsamlinger hviler — lamellen bærer sin last på listen og drageren, så skruerne er ren lås. Derfor er 15 mm fat rigeligt.

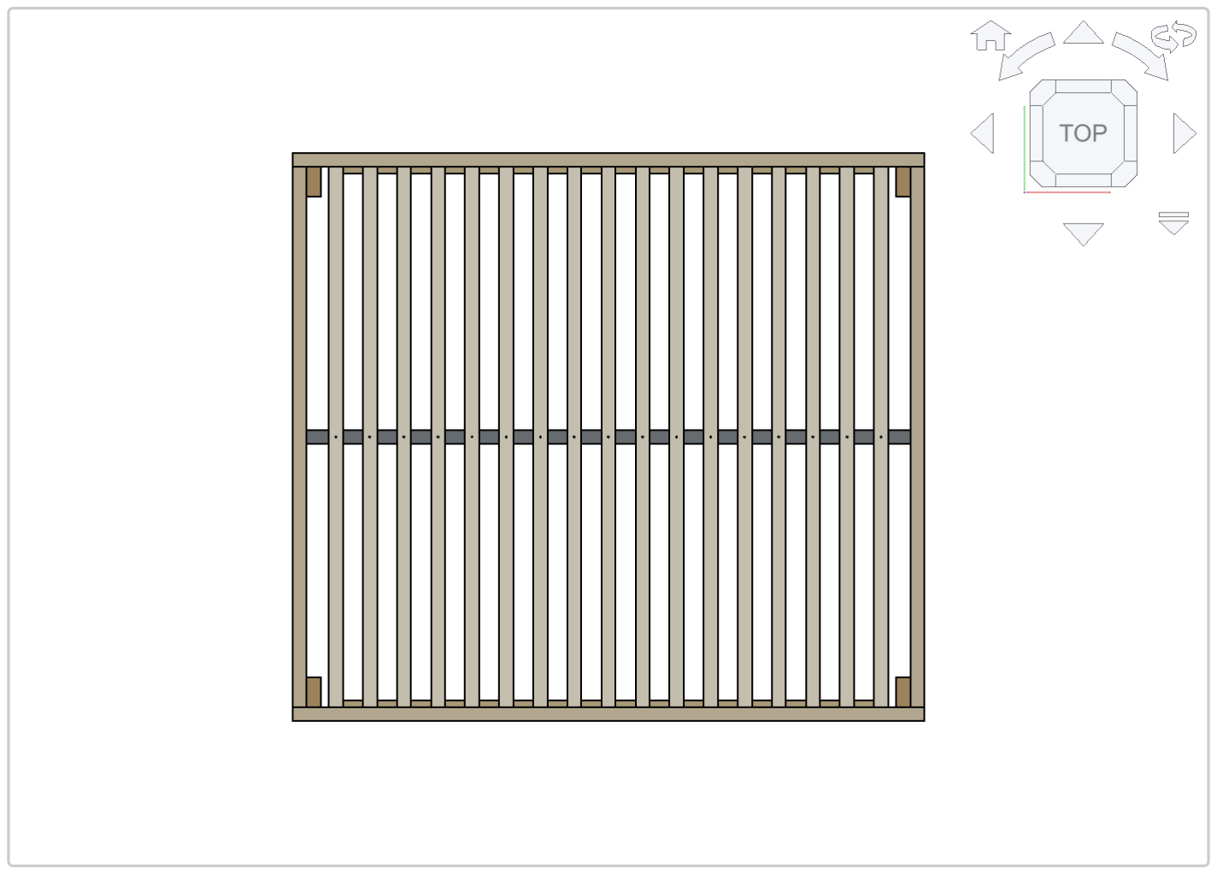
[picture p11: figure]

Færdigt lamelfelt set ovenfra — 17 lameller, c/c 107,8 mm

Trin 6 · Kontrol og efterspænding

Står den plant? Vipper sengen, sæt en tynd skive under det ene ben eller slib 1 mm af. Gulvet er sjældent plant, og benene er af afskær.

1.
2.

3.

4.

•

Kør en hånd over lamellerne. Intet skruehoved må rage op — det er det, madrassen og betrækket ligger på.
Slib kanterne let på ramme og lameller med sandpapir 120. Det sparer futonens betræk. Efterspænd de 8 M10-bolte efter 2–4 uger og igen efter en fyringssæson. Ubehandlet fyr svinder, og det er derfor kontramøtrikkerne sidder der.
Sengen er tænkt ubehandlet. Vil du olie eller sæbebehandle den, gør det før samling, mens delene er løse.

•

•
•

•

## 7 · Holder det til to personer?

Kort statik-tjek for fyr (E ≈ 10 GPa), regnet på den byggede geometri. Grænsen L/300 er den normale komfortgrænse for en sengebund:

Del | Frit spænd | Nedbøjning ved fuld last | Grænse L/300
Lamel 45 × 45 | 810 mm | ~1,7 mm (50 kg punktlast midt på ét fag) | 2,7 mm
Midterdrager 45 × 45 | 2 fag à 955 mm | ~3–4 mm pr. fag | ~3,2 mm
Vange 45 × 95 | 1910 mm | 1–2 mm | ~6,4 mm

Lamellerne er kontinuerte over drageren, hvilket gør dem stivere endnu, og et kvadratisk tværsnit (slankhed 1:1) kan ikke vælte — domino-problemet fra høje, tynde lameller findes ikke her. Drageren er et grænsetilfælde lige omkring L/300. Uproblematisk under en eftergivende futon, men vil du have mere margin: sæt drageren på højkant som 45 × 70 — så falder frihøjden under midten fra 205 til 180 mm, altså under de 20 cm — eller sæt et midterben mere i, hvilket ikke koster frihøjde.
Boltene er kraftigt overdimensionerede. Belastningen er ~2,3 kN fordelt på fire hjørner, altså ~600 N pr. hjørne på to bolte. Grænsen sættes ikke af bolten (en M8 kan ~8,8 kN i forskydning) men af træets hulrandstyrke: 8 mm × 45 mm × ~25 MPa ≈ 9 kN — 15 gange over behovet. Derfor er M8 rigeligt på endestykke-aksen, og derfor betyder de 2 mm op til M10 ingenting. Det, der betyder noget, er skivens størrelse.

Vil du ændre noget?

Færre lameller: 16 stk. sparer ~1,7 kg og giver ~71 mm spalte — fint i den brede ende for en blød futon. Både lamellængder og støttelistens hulmønster skal så regnes om.
Stivere midte: et ekstra midterben er den billige vej — det koster ét hul og ingen frihøjde. En 45 × 70-drager på højkant er stivere endnu, men efterlader kun 180 mm under midten.
Anden madras: rammen er madrasmålet. Ændrer du det, ændrer vanger (2000), endestykker/ lameller (1710) og drager (1910) sig alle sammen.

Forbehold

Pris: træet er prischecket til 1.376,40 kr hos Silvan og vange-boltene til 159,80 kr hos jem&fix (juli 2026). Skruer og beslag er fire pakker, som ikke er prischecket — regn med ~1.650 kr i alt. 45×45-lameller er dyre pr. bræt, men benene er gratis.
Ben af afskær: ben-tværsnittet er 45 × 95, hvilket er slankt for et sengeben. Det holder, fordi rammen er en stiv boltet kasse, så benene står i ren tryk. Valget er også praktisk: der fandtes ingen firkantet, ubehandlet stolpe hos jem&fix, Silvan eller Bauhaus — alle massive stolper er trykimprægnerede eller malede.
Lamelspalte ~63 mm og åbningsareal ~58 %. God udluftning nedefra og uproblematisk for en futon; til en tynd madras uden futon-fylde ville man vælge tættere lameller.

•

•

•

•

•

•

## 8 · Tegninger

De fire ark bagest er målsatte og hører til hvert sit trin:

Ark | Brug det til
Tegning — mål, plan og opstalt | overblik og kontrolmål (afsnit 1 og 4)
Boreplan — bolte og skruer | benene, vangerne og endestykkerne (afsnit 5 A)
Boreplan — støttelistens lamelhuller | alle 34 hulafstande, målt fra listens ene ende
Boreplan — midterdrager → endestykke | vinkelbeslagets placering (trin 4)

Mål alle 34 lamelhuller fra samme ende med båndmål — step ikke 107,8 mm 16 gange, så hober fejlen sig op. Kontrolmål: første hul 10,5 mm inde, sidste 10,5 mm fra den anden ende, midterste lamel præcis på 885 mm.

Model, tegninger og boreplaner er genereret fra en parametrisk FreeCAD-model ( scripts/build_bed_let.py → cad/seng_let.FCStd ). Alle mål i vejledningen er hentet fra den byggede model. Ændrer du dimensioner eller lamelantal, skal tegninger og boreplaner genereres om.

## Tegning — mål, plan og opstalt

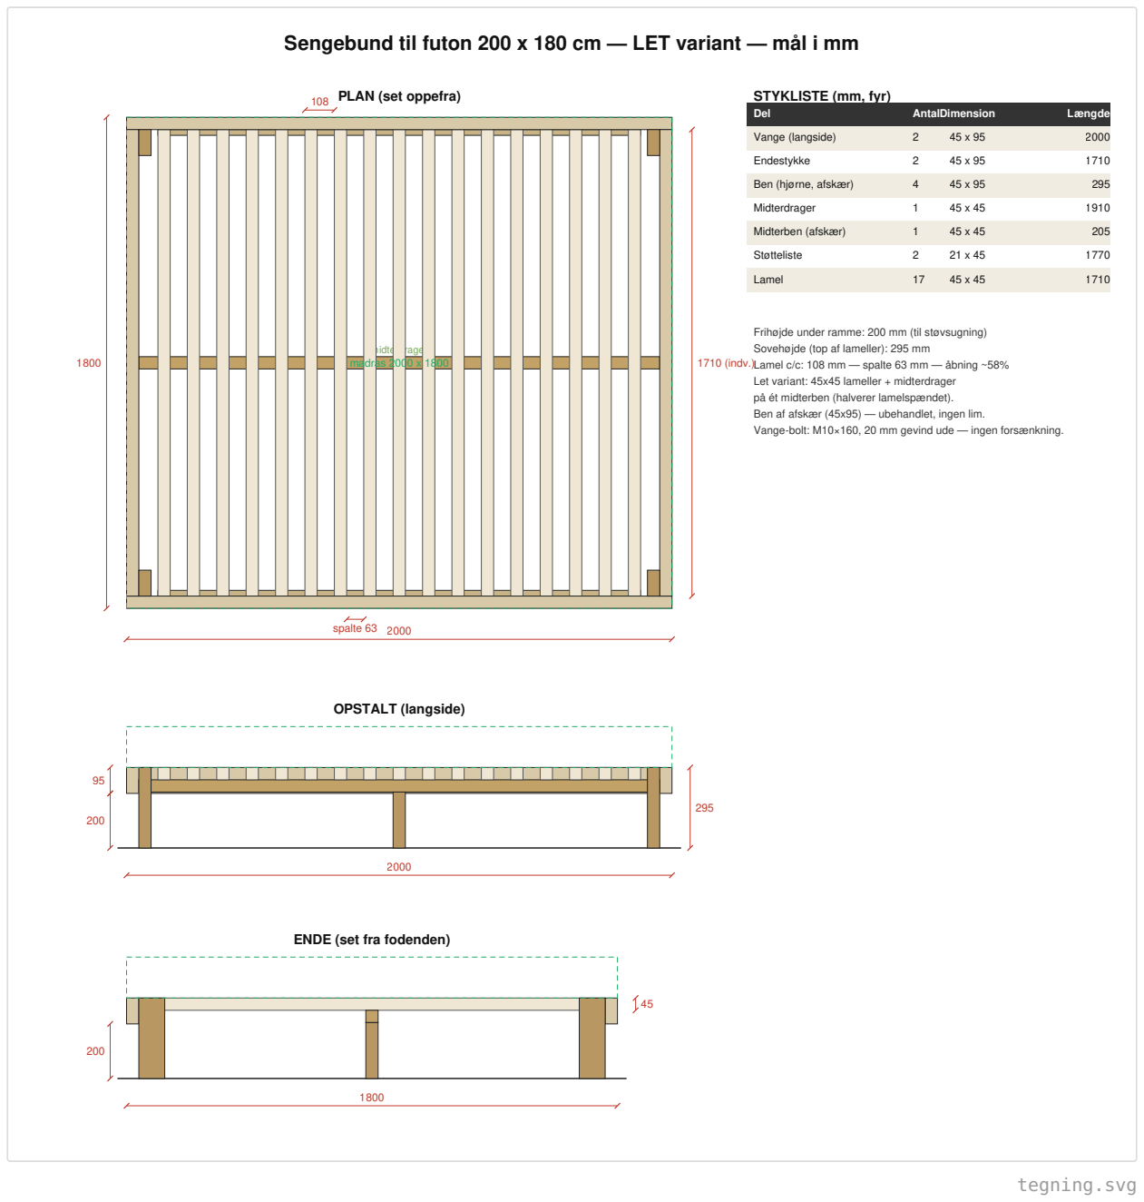
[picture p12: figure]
tegning.svg; PLAN (set oppefra); midterdrager madras 2000 x 1800; 1710 (indv.); spalte 63; OPSTALT (langside); ENDE (set fra fodenden); STYKLISTE (mm, fyr); Del; AntalDimension; Længde; Vange (langside); Endestykke; Ben (hjørne, afskær); Midterdrager; Midterben (afskær); Støtteliste; Lamel; Sovehøjde (top af lameller): 295 mm; på ét midterben (halverer lamelspændet).

Sengebund til futon 200 x 180 cm — LET variant — mål i mm

Frihøjde under ramme: 200 mm (til støvsugning)

Lamel c/c: 108 mm — spalte 63 mm — åbning ~58% Let variant: 45x45 lameller + midterdrager

Ben af afskær (45x95) — ubehandlet, ingen lim.
Vange-bolt: M10×160, 20 mm gevind ude — ingen forsænkning.

## Boreplan — bolte og skruer

boreplan.svg

Boreplan — LET variant, futon 200 × 180 cm (mål i mm)

A · Lamelhuller — plan (op gennem støttelisten)

liste 21

lamel 0 | lamel 1 | lamel 2

108 (c/c lameller)

24

45

63
2 spånskruer 4,5 × 60 pr. ende — lodret gennem listens 45 mm HØJDE + 15 mm op i lamellen. Ø5 GENNEMGANG i listen (= afstands-jig) · Ø3 pilot 20 mm i lamellen · Ø10 forsænk under listen.

BORDIAMETRE — fyr/gran, spånskruer

Ø5 | gennemgang, 4,5 mm skruer — altid
Ø5,5 | gennemgang, de 6 stk. 5 mm skruer
Ø3 | pilot i den FJERNE del (4,5 mm skruer)
Ø3,5 | pilot i ENDETRÆ (5 mm skruer), 40 mm
Ø10 | forsænk, 4,5-hoveder (Ø9)
Ø11 | forsænk, 5,0-hoveder (Ø10)
Ø2,5 | pilot til vinkelbeslagets korte skruer
Ø12 | boltehul, M10×160 på vange-aksen
Ø10 | boltehul, M8×100 på endestykke-aksen

Gennemgang = skruediameter + 0,5 mm · pilot ≈ 65 % af Ø. Uden gennemgangshul griber gevindet i den nære del og jækker delene fra hinanden i stedet for at spænde dem sammen. Forsænk med ÉN kegleforsænker 90° Ø16: Ø16 er keglens største mål, ikke hullets — Ø10/Ø11 er to dybder.

Længder: 4,5×60 til lamellerne · 4,5×50 KUN til støtteliste→vange · 5×80 til de 6 i ENDETRÆ.

BOR-LÆNGDER (gennemgang/pilot-dybde):
Ø5 21–45 · Ø5,5 45 · Ø3 20–35 · Ø3,5 40 · Ø2,5 ≈15 (mm)
Ø10 90 mm gennem · Ø12 140 mm gennem — kræver LANGT bor!

B · Støtteliste → vange — huller langs listen (6 stk)

190
330 (c/c)

1770 (liste)

6 × spånskrue 4,5 × 50 fra listens inderside vandret ind i vangen (skjult under lamellerne).
IKKE 70 her: 21 mm liste + 45 mm vange = 66 mm stak — en 70'er stikker 4 mm ud på vangens yderside. Ø5 GENNEMGANG i listen · Ø3 pilot 35 mm i vangen · Ø10 forsænk i listens inderside.

C · Hjørne (vange-akse) — bolt gennem 45+95 mm ben

vange

ben 45×95

gulv

skive + møtrik
+ kontramøtrik
INGEN forsænkning

230

275

30

45

200

Ø12 hul gennem 140 mm (45+95)

VANGE-AKSE: M10×160 bolt gennem vange (45) + ben (95) = 140 mm træ. Der stikker 20 mm ud på benets inderside:
skive 2,5 + møtrik 8 + KONTRAMØTRIK 8 = 18,5 mm — reelt plant. INGEN forsænkning (en M10×140 har nul gevind til møtrikken).

ENDESTYKKE-AKSE (vinkelret): M8×100 i Ø10-hul gennem endestykke (45) + ben (45) = 90 mm — møtrik + STOR skive fladt, INGEN forsænkning (en 140 mm bolt ville stritte ~50 mm ind under lamellen). Højder 15/50, forskudt fra vange-boltene (230/275).

C2 · Hjørne (endestykke-akse)
bolt gennem 45+45 mm ben

ende

ben 45×95

skive + møtrik
INGEN forsænkning

215

250

15

35

Ø10 gennem 90 mm (45+45)

Se tekst ved Panel C: M8×100, INGEN forsænkning, forskudt 15/50 fra vange-boltene (kryds i benet).

D · Boltplacering på vange og endestykke — opstalt udefra

VANGE udefra (2 stk, ens i begge ender)

67 | 67

30

45

4 × M10×160 gennemgående pr. vange (gennem 45+95=140 mm træ). Højder fra underkant. INGEN forsænkning: M10×160 stikker 20 mm ud på benets INDERSIDE til skive + 2 møtrikker.

ENDESTYKKE udefra (2 stk)

47 | 47
855 (midt)

15

35

M8×100 hjørnebolte i Ø10-hul, højde 15/50 (gennem 45+45=90 mm ben, møtrik + stor skive fladt, INGEN forsænkning).
Blå: 2 skruer 5×80 midtfor i højde 23/47 ind i midterdragerens ENDETRÆ (+ vinkelbeslag) — Ø5,5 gennemgang i endestykket, Ø3,5 pilot i endetræet.
Lamel → midterdrager: 1 skrue 4,5×60 lodret ned midt i hver lamel, langs dragerens centerlinje —
Ø5 gennem lamellen, forsænk 2–3 mm UNDER sovefladen. Midterdrager → midterben: 2 skruer 5×80 lodret ned, Ø3,5 pilot i benets endetræ (kun 7,5 mm til kanten!).

## Boreplan — støttelistens lamelhuller

liste_boreplan.svg

Støtteliste — boreplan for lamelhuller (2 stk, ens · mål i mm)

A · Støttelistens UNDERSIDE (21 × 1770) — 34 lamelhuller, Ø5 gennemgang

Længden er i skala ca. 1:1 · de 21 mm er overdrevet i højden. Begge lister bores ens.

107,8 (c/c lameller)

24

0 →

L0 | L1 | L2 | L3 | L4 | L5 | L6 | L7 | L8

10,5

885 →

L8 | L9 | L10 | L11 | L12 | L13 | L14 | L15 | L16

10,5

← 1770

Lamelhullerne ligger symmetrisk om listens midte (10,5 mm inde i begge ender), men vange-hullerne i panel D gør IKKE — vend derfor begge lister samme vej: 0-enden mod samme gavl.

B · Snit gennem samlingen (ca. 2,5:1) — hvor i de 21 mm sidder hullet

vange

45 × 95

lamel — 45 mm høj,

løber på tværs →

kote 200 (rammens underkant)

295 = soveflade

10,5 10,5

21 (listens tykkelse)

45

15

Ø3 pilot 20 mm

Ø5

Ø10 forsænk

støtteliste 21 × 45

Skruen er 4,5 × 60 spånskrue, LODRET op:

45 mm gennem listens HØJDE + 15 mm op i lamellen = 60. Den bryder altså ikke ud i sovefladen ved kote 295.

Hullet ligger midt i de 21 mm → 8 mm træ til hver side af
et Ø5-hul. Bor derfor LODRET (borelære/søjleboremaskine): en skæv Ø5 gennem 45 mm bryder ud i listens side.

Bor listen FØR den skrues på vangen — de forborede huller er selv afstands-jiggen, der placerer lamellerne.

Lamellen HVILER på listens overkant, så skruen bærer ingen vægt; den er ren lås mod at lamellen løfter sig.

D · Støttelistens INDERSIDE (45 × 1770) — de 6 vandrette huller til vangen

75 | 330 (c/c)

1770 (liste)

45

Spånskrue 4,5 × 50 (IKKE 60/70 — 21 + 45 = 66 mm stak). Ø5 gennem listen, Ø3 i vangen, Ø10 forsænk. Højde: midt i de 45 = 22,5 mm.
⚠ Vange-hullet ved 1725 mm og lamelhullet ved 1735,5 mm ligger kun 10,5 mm fra hinanden — ca. 5,5 mm træ mellem de to Ø5-huller. Bor begge, før du skruer.

C · Målskema — afstand fra listens VENSTRE ende (mm)

Mål alle 34 fra samme ende med båndmål — step ikke 107,8 af 16 gange, fejlen hober sig op. Afrunding til hele mm er rigeligt.

lamel | hul 1 | hul 2
L0 | 10 | 34
L1 | 118 | 142
L2 | 226 | 250
L3 | 334 | 358
L4 | 442 | 466
L5 | 550 | 574
L6 | 657 | 681
L7 | 765 | 789
L8 | 873 | 897
lamel | hul 1 | hul 2
L9 | 981 | 1005
L10 | 1089 | 1113
L11 | 1196 | 1220
L12 | 1304 | 1328
L13 | 1412 | 1436
L14 | 1520 | 1544
L15 | 1628 | 1652
L16 | 1736 | 1760

34 huller pr. liste · 2 lister = 68 huller i alt. Parret sidder 24 mm fra hinanden, centreret på lamellens 45 mm fod.
Kontrolmål: første hul 10,5 og sidste hul 1759,5 — begge 10,5 mm fra hver sin ende. Rammer det ikke, er listen skåret forkert (skal være 1770 mm). Midterste lamel (L8) sidder præcis på 885 mm = listens midte.

## Boreplan — midterdrager → endestykke (vinkelbeslag)

drager_boreplan.svg

Midterdrager → endestykke — vinkelbeslag (mål i mm)

endestykke | lamel 0

midterdrager
2 × 5×80 (kote 223/247)

50

50

115 (hjørnezone)

Blåt = vinkelbeslag (Simpson AC35350) — 2 stk. i alt (1 pr. ende).
Monteret PÅ SIDEN af drageren, ikke ovenpå/under: bevarer de 205 mm frihøjde under midten.

Vinge 1 mod endestykkets inderside (skruer vandret, som de to 5×80) — vinge 2 mod dragerens sideflade. Beslaget sidder i kote 210–245 (centreret i dragerens 45 mm højde); begge vinger skrues vandret ind i sidetræ. Fastgørelse: Simpson TTUFP 4,0×20 beslagskruer, FLADT hoved (ikke undersænket) — Ø2,5 pilothul.
Begge beslag sidder samme side (mod vange A) — vælg i praksis den side der er nemmest at komme til.

Simpsons datablad anbefaler 2 beslag pr. samling (ét i hver side); denne BOM har kun 2 stk. i alt (1 pr. ende). Overvej 2 ekstra beslag, hvis fuld anbefaling ønskes — koster lidt, øger sikkerhedsmargin på samlingen.

REFERENCE — Simpson AC35350 vinkelbeslag

A = B = 50 mm · C (vinge-bredde) = 35 mm · t = 2 mm, varmforzinket stål
4 × Ø5 + 1 × Ø8,5 pr. vinge — Ø8,5-hullet er kun til M8-bolt (beton), bruges ikke her. Hulplacering her er skematisk (efter produktfoto) — se Simpson-databladet for eksakte mål. Brug de 4 × Ø5-huller pr. vinge til TTUFP-beslagskruerne.

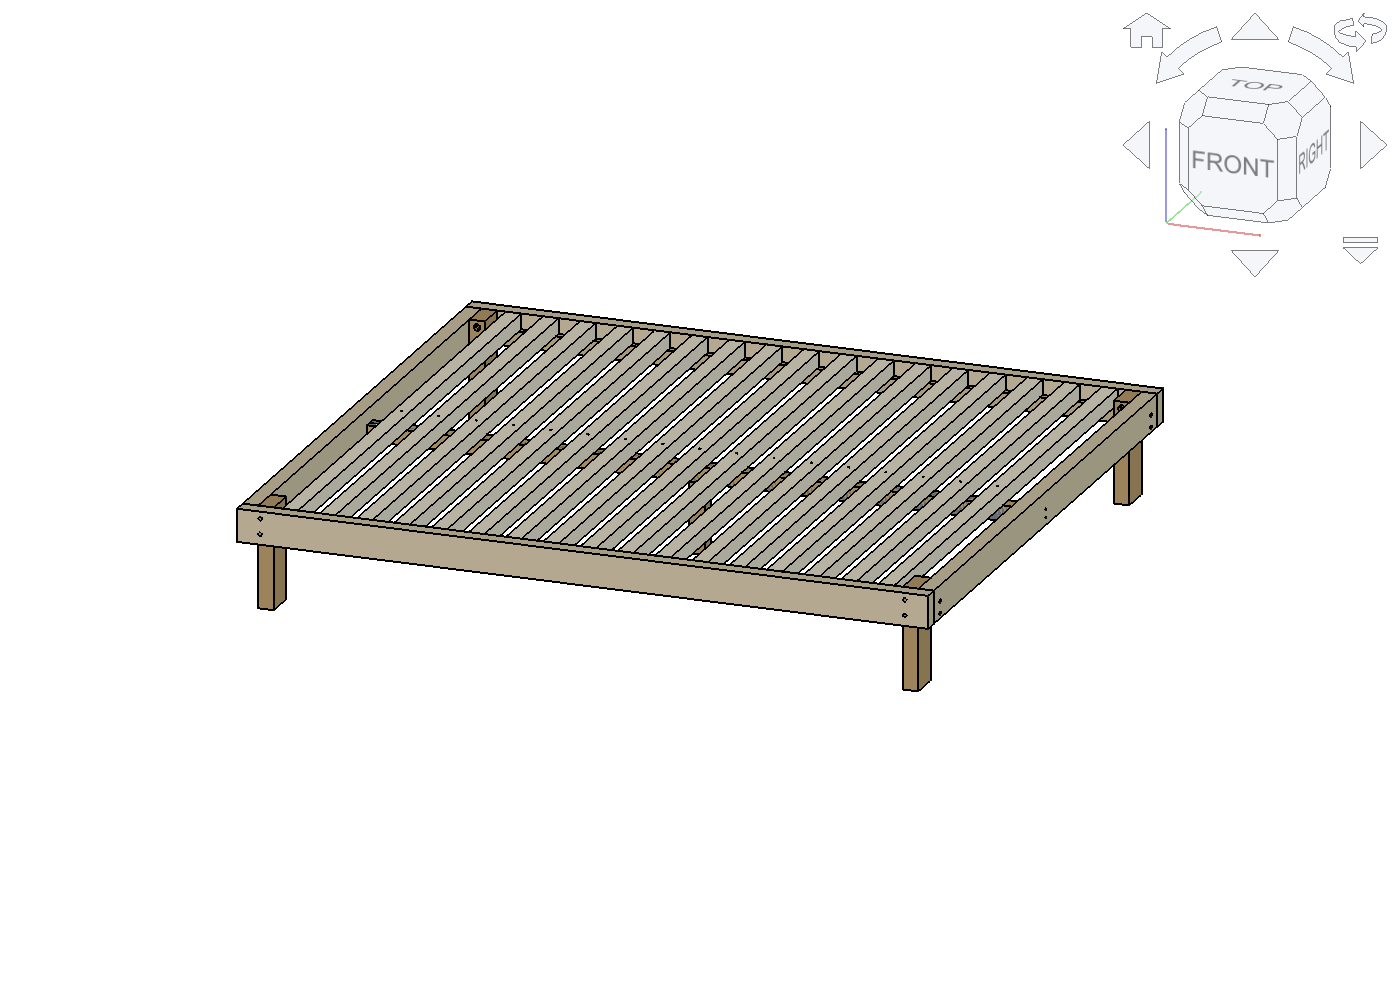
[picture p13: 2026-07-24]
cad/screenshots/seng_let_05_dimetrisk.png

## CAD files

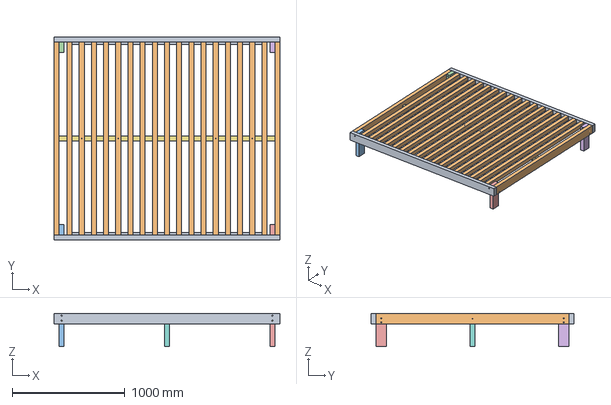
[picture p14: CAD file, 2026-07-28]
cad/seng_let.step
2000.0 x 1800.0 x 295.0 mm

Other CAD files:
cad/seng_let.FCStd

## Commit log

2026-07-23 flyt huller
    [seng.FCStd, seng.step]
2026-07-24 seng let efter reveiw
    [seng_let.FCStd, seng_let.step]
2026-07-24 Boreplan: placeringsmål + afsnit D, detaljebilleder til let variant
    - make_drilling_plan_let.py: afsnit C får 30/45-mål fra vangens
    underkant; nyt afsnit D viser vange- og endestykke-boltplaceringer
    udefra (80/35 fra ende, højder fra underkant) samt midterdrager-
    skruerne gennem endestykket (905/23/47).
    - add_drawing_page_let.py: skalér boreplan til ny SVG-højde; brug
    App.getResourceDir() til TechDraw-skabeloner (snap 2620 flyttede stien).
    - Genindlejr boreplan i seng_let.FCStd; gem præsentationsfarver.
    - cad/screenshots: 10 præsentations-/detaljebilleder (træfarver,
    hvid baggrund), inkl. målsatte borepositioner på vange, endestykke
    og midterdrager.
    - .gitignore: ignor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
    [seng_let.FCStd]
2026-07-24 nye ben
    [seng_let.FCStd, seng_let.step]
2026-07-24 Fjern standard/tung sengedesign — kun let variant tilbage
    Projektet fokuserer nu udelukkende på den lette futon-sengebund.
    Fjernet (standard-designet):
    - Docs: BOM.md, sengebund_med_stoetteliste.md
    - Scripts: build_bed.py, make_drawing.py, make_drilling_plan.py,
    add_drawing_page.py
    - CAD: seng.FCStd, seng.step, seng_boreplan.svg, seng_tegning.svg
    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
    [seng.FCStd, seng.step]
2026-07-24 Redesign LET-seng: flush lameller, 180×200, drager 45×45 + docs/PDF/README
    Designændringer (fra parametre i build_bed_let.py):
    - Lameller flugter nu med rammens overkant (sovflade 315→295 mm),
    støtteliste sænket tilsvarende.
    - Udvendige mål 180×200 cm = madrasmålet (outer_len 2010→2000,
    outer_w 1900→1800), madras ligger plant af med kanten.
    - Midterdrager 45×70→45×45 (samme profil som lameller): bevarer 205 mm
    frihøjde under midten, forenkler BOM. Grænsetilfælde om L/300 dokumenteret.
    Fixes:
    - Midterdrageren fik aldrig skåret sine huller pga. navnekollision mellem
    gruppen og box-objektet (getObjectsByLabel returnerede gruppen). Refereres
    nu direkte fra box().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
    [seng_let.FCStd, seng_let.step]
2026-07-24 scripts: derive paths from __file__ (remove hardcoded /home/dalager)
    Makes the build/drawing scripts portable for anyone cloning the repo, and
    drops the baked-in home-directory path before publishing publicly.
    [seng_let.FCStd, seng_let.step]
2026-07-26 Ret skruelængder, fjern Ø20-forsænkningen, ny boreplan for støttelisten
    Fastgørelsesskemaet var forkert på ét punkt: støtteliste → vange brugte
    4,5 × 70 gennem en stak på 21 + 45 = 66 mm. Skruen ville stikke igennem.
    Skruerne er samtidig lagt om til det, der faktisk kan købes:
    lamel → liste / drager 4,5 × 60 spånskrue (var 4,5 × 70)
    liste → vange 4,5 × 50 spånskrue (var 4,5 × 70)
    endetræssamlinger 5,0 × 80 spånskrue (var 4,5 × 70)
    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
    [seng_let.FCStd, seng_let.step]
2026-07-30 Ny boreplan for midterdrager -> endestykke (vinkelbeslag)
    Vinkelbeslaget (Simpson AC35350) fandtes kun i tekst i BOM/sengebund-docs.
    Ny boreplan (egen fil/side, seng_let_drager_boreplan.svg) viser midterdrager,
    beslagets placering (montage på siden af drageren) og huller i forhold til
    endestykkerne, med reelle mål/hulmønster fra Simpson-databladet.
2026-07-30 Omskriv dokumentationen til en byggevejledning
    PDF'en blev bygget af sengebund_let.md + BOM_let.md, som overlappede
    hinanden: forborings- og fastgørelsesskemaet stod to gange, borlisten to
    gange, Ø11-forsænkningen tre gange, M10x160-argumentet fire gange. Store
    dele af teksten diskuterede med tidligere versioner af sig selv
    ("tidligere versioner bad om...", "de allerede købte M10x140 skal
    byttes") og henviste til kildekode. Og der var ingen samlerækkefølge.
    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
2026-08-02 Flyt genererede tegninger og PDF fra cad/ til docs/
    cad/ indeholder nu kun CAD-kilder (.FCStd, .step, screenshots), mens docs/
    rummer det genererede output: de fire målsatte SVG-tegninger og
    dokumentation.pdf. Filnavnene taber seng_let-præfikset — det var overflødigt,
    når mappen siger det samme.
    .gitignore ignorerede hele docs/, så tegningerne aldrig blev versionsstyret.
    Nu ignoreres kun docs/*.png og docs/*.jpg, altså referencefotos af beslag og
    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
2026-08-02 Afsnit om at vælge træ, der er lige
    Sengen er bygget, og under samlingen viste det sig, at vrid i vangerne og
    endestykkerne forplanter sig synligt gennem hele rammen: hjørnerne kommer
    skævt sammen, benene hælder en anelse, og støttelistens overkant følger
    vangens vrid, så lamelfladen ikke bliver helt plan. Konstruktionen holder —
    de boltede hjørner tvinger træet på plads — men det kan ses, og vejledningen
    sagde intet om trækvalitet ved indkøb.
    Nyt afsnit i §2 Indkøb: sigt langs brættet fra enden på både flade og
    højkant, de fire fejltyper rangeret efter hvad de betyder her (vrid værst og
    kan ikke skrues væk, skålning ligegyldig), hvorfor det især er de fire 45×95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
